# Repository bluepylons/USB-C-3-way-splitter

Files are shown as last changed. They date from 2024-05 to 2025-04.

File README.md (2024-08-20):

# A USB-C 3-way-splitter for charging multiple 5W devices from a single USB-PD charger

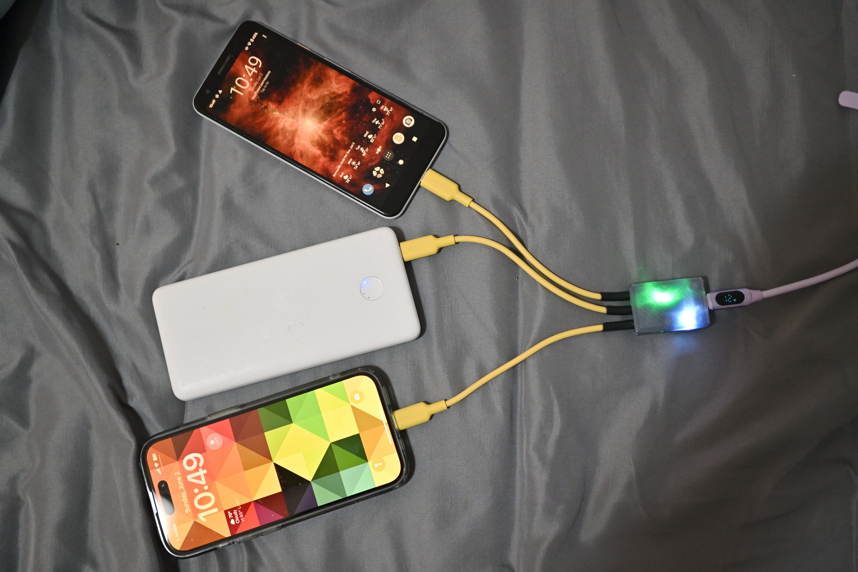
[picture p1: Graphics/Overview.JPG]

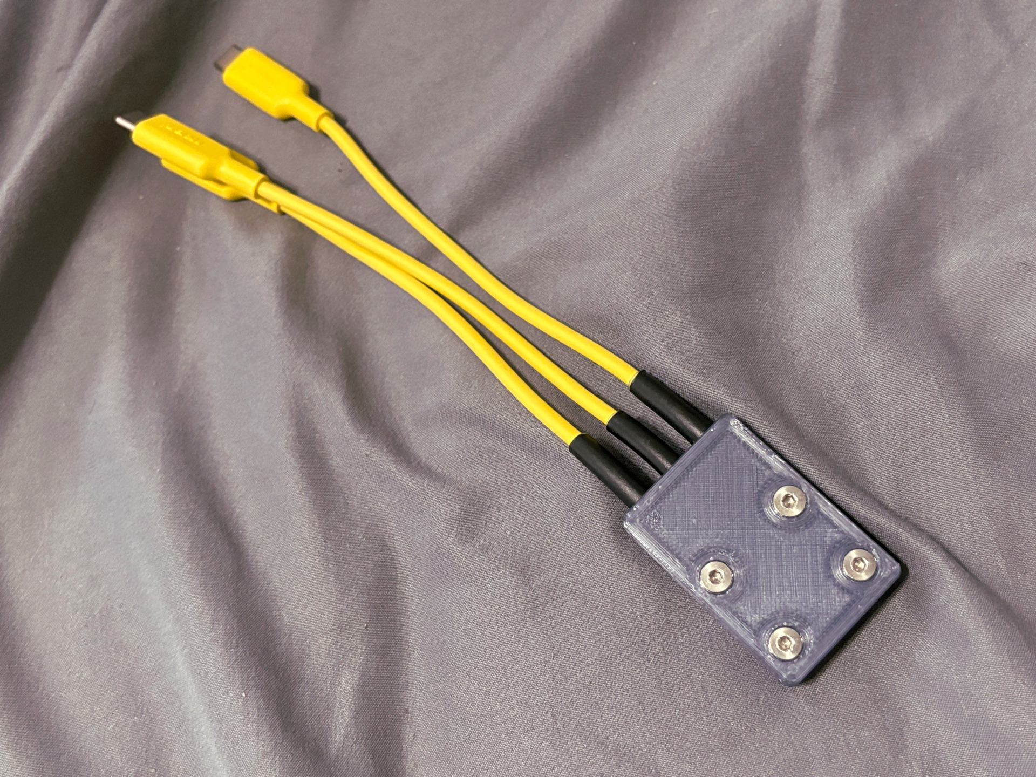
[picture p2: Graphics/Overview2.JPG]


*Disclaimer* - **Build and/or use this at your own  risk. I am not responsible for anything that arises from use of these files or documents, or for anything that arises from constructing and/or using this device.**

*Disclaimer 2* - the USB battery charging standard actually provides [for a maximum of 1.5A](https://imgur.com/07zPKKw), not 1A as originally believed. The polyfuse used (Littelfuse 1812L300MR) does not reliably trip below 5A, so this splitter may result in 4.5A maximum being drawn from the source. A planned Version 4 (which uses an 3A electronic fuse in place of the high-side switch to reliabily cut off current at around 3A) is being developed to address this issue. UPDATE August 19, 2024 - Version 4 does not work as the ENABLE pin logic for the electronic fuse was inverted. Version 5 is planned to fix this. 

This is a USB-C splitter that splits a 5V 3A-capable USB-C power source to 3 5V 1A  sources. This is for using a single-port USB-C PD charger to charge multiple 5V USB-C devices at once. Files are done in KiCAD 8, and manufacturing files for JLCPCB are provided. An enclosure design is included (which was designed in Autodesk Fusion 360) - .3mf, .step, and .f3z file are provided. 

This design has been prototyped and  tested. 

## Background
With the widespread adoption of USB-C for device charging, I can now travel with a single compact 45W USB-C GaN charger and cable, and charge all my USB-C devices (phone, laptop, camera, flashlight, power bank, headphones, etc.) with that one charger. However, having a single cable and single charger is often limiting when I need to charge multiple devices, especially overnight, and many USB-C devices only need 5V and not many watts for overnight charging. This splitter goes onto an existing USB-C cable, for charging those devices simultaneously with a single charger, without needing a bulkier multi-port charger and multiple cables. 

## Operation 
For safety, the splitter outputs only power on when the splitter is connected to a charger that indicates it can actually supply 3A, and includes a resettable fuse for overcurrent protection. The white LED lights up when it is connected to a powered USB-C cable. The green LED lights up if the power source is capable of supplying 5V 3A, and indicates the outputs have been powered on.

The outputs have D+ and D- shorted to indicate that they can supply ~~~1A~~~ 1.5A of current (per the USB Battery Charging standard). 

## Design
The splitter only powers on with USB-C inputs capable of supplying 5V 3A. This is done by monitoring the USB-C CC lines and checking that the signal there is greater than 1.25V. Under the USB-PD standard, if the voltage on the CC pin [is greater than 1.31V](https://hackaday.com/2023/01/04/all-about-usb-c-resistors-and-emarkers/), it indicates the source is capable of supplying 5V 3A. Only then are the outputs powered on (as indicated by the green LED). Otherwise, the outputs are turned off. 

The CC line voltage checking is done by a pair of comparators that monitor each of the 2 CC lines (as the USB-C input cable can be plugged in either way). The CC line voltage are compared against a 1.25V reference voltage (provided by an ST TS4061AICT-1.25 shunt diode reference) - a 1.31V voltage reference would have been more precise, but were not easily available, and 1.25V is above the 1.16V cutoff for a 1.5A source and works fine. The output of the comparators are fed through a pair of diodes (functioning as an OR gate) to the ENABLE input on an SiP32509 high-side switch that turns the outputs on and off. The device is over-current protected by a 3A resettable fuse (Littelfuse 1812L300MR). The CC lines and +5V bus are ESD protected with an SRV05-4 ESD diode array and an ESD5Z5V0 TVS diode.

Note that the output cables need 56K pull-up resistors between output CC and 5V to comply with the USB-C protocol - some devices may not charge if these resistors are missing. USB-A to USB-C cables are required to include this resistor, so using the USB-C end from a cut-up USB-A to C cable is recommended for the output cables. 

A 3D-printed enclosure design is supplied in the Enclosure folder. The enclosure design is meant to be 3D-printed in two halves; on mine these were printed with translucent PETG to allow the indicator LEDs to shine through. The lower enclosure features embedded M3 nuts - **the print must be paused at the appropriate layer and M3 nuts need to be inserted before the print resumes**. The two halves are screwed together with M3x8 countersunk screws. The enclosure is designed to use [Ikea  SITTBRUNN](https://www.ikea.com/us/en/p/sittbrunn-usb-a-to-usb-c-light-yellow-80539483/) USB-A to USB-C cables, as these are widely available and inexpensive. The ends are wrapped in Qualtek Q5-3X-3/16-01-QB48IN-25 adhesive heatshrink for strain relief. To dissipate heat from the SiP32509 high-side switch (U2), which is expected to generate about 0.4W of heat at 3A, either the enclosure must be potted to facilitate heat transfer, or a thermal pad must be used between the SiP32509 and the case. [Lower-enclosure-potted](https://github.com/bluepylons/USB-C-3-way-splitter/blob/main/Enclosure/Lower-enclosure-potted.3mf) has a small hole to inject potting compound (or hot glue, or silicone) into the case - use a high viscosity potting compound to avoid it getting in the input USB-C connector. [Lower-enclosure-thermal-pad](https://github.com/bluepylons/USB-C-3-way-splitter/blob/main/Enclosure/Lower-enclosure-thermal-pad.3mf) has a small raised feature above the SiP32509 IC to place a 1.5mm thick thermal pad between it and the case. 

# ORDERING GUIDE

## Bill Of Materials

### Custom Parts
| Description | Quantity  | Notes | 
| --- | --- | - |
| [PCB](https://github.com/bluepylons/USB-C-3-way-splitter/tree/main/Manufacturing%20files) | 1 | See "Ordering the PCB" section below  | 
| [Upper enclosure](https://github.com/bluepylons/USB-C-3-way-splitter/blob/main/Enclosure/Upper-enclosure.3mf) | 1 | FDM 3D-printed  |
| Lower enclosure ([thermal pad](https://github.com/bluepylons/USB-C-3-way-splitter/blob/main/Enclosure/Lower-enclosure-thermal-pad.3mf) or [potted](https://github.com/bluepylons/USB-C-3-way-splitter/blob/main/Enclosure/Lower-enclosure-potted.3mf)) | 1 | FDM 3D-printed. Has 4 embedded M3 nuts, which must be installed while 3D printing | 

The 3D-printed parts were FDM 3D-printed in PETG, though other materials probably work fine here. A translucent or semi-translucent material is recommended so that the indicator LEDs can shine through. 

## Off-the-shelf parts

| Description | Part number | Quantity | Notes | 
| --- | --- | --- | --- |
| [Ikea Sittbrunn USB-A to USB-C cable](https://www.ikea.com/us/en/p/sittbrunn-usb-a-to-usb-c-light-yellow-80539483/) | Ikea 805.394.83 | 3 | | 
| M3 hex nut, DIN 934, zinc-plated steel | McMaster-Carr 90591A250 | 4 | Generic. Not stainless steel to avoid galling |
| M3x8 flat head screw, DIN 7991 / ISO 10642, hex drive, 18-8 stainless steel | McMaster-Carr 92125A128 | 4 | Generic |
| Adhesive-lined heat-shrink, 3/16" / 4.8mm ID, 3:1 shrink ratio | Qualtek Qualtek Q5-3X-3/16-01-QB48IN-25  | 3x 25mm  | |

If you are using the [thermal pad option](https://github.com/bluepylons/USB-C-3-way-splitter/blob/main/Enclosure/Lower-enclosure-thermal-pad.3mf) for the lower enclosure, you will need 1.5mm thick thermal pads. I used Thermalright Extreme Odyssey 1.5mm pads for the ones I have built, but other 1.5mm thermal pads (e.g. Arctic TP-3) may work. The thermal pad must not be electrically conductive. 

If you are using the [potted option](https://github.com/bluepylons/USB-C-3-way-splitter/blob/main/Enclosure/Lower-enclosure-potted.3mf) for the lower enclosure, you will need some sort of potting compound that can be injected through a 5mm diameter hole. The ones I built used hot glue. Make sure the potting compound has high enough viscosity to not get into the input USB-C port. 

## Ordering the PCB

The PCB can be ordered from [JLCPCB](https://jlcpcb.com/) in China, and the files are provided in their format. 

1.)  Go to JLCPCB, and press "Order Now". 
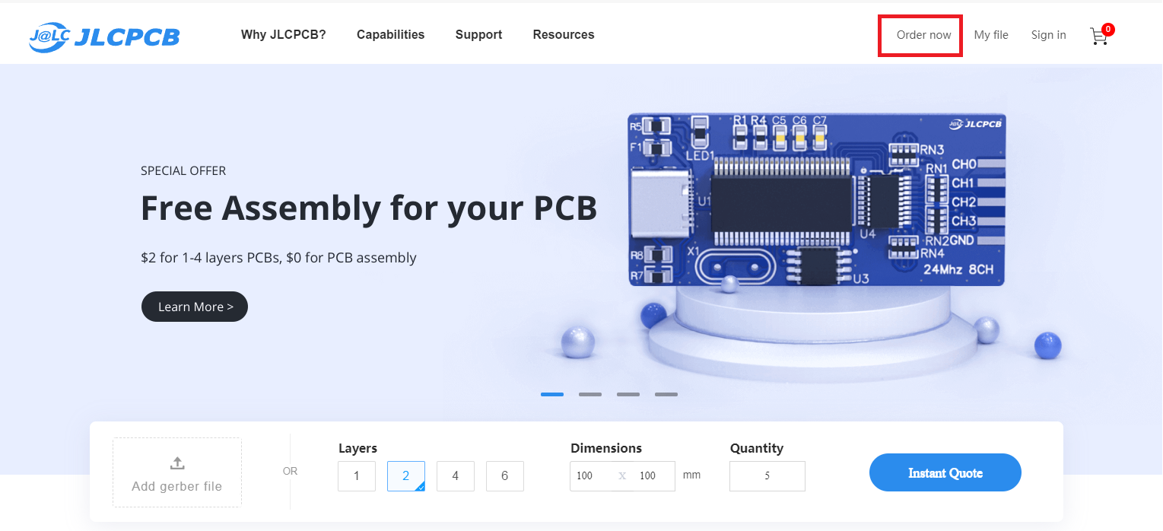
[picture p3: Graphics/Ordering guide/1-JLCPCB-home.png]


2.) Next, you want to upload the [Gerber ZIP file](https://github.com/bluepylons/USB-C-3-way-splitter/blob/main/PCB%20manufacturing%20files/V3%20Gerbers.zip) for the PCB. 
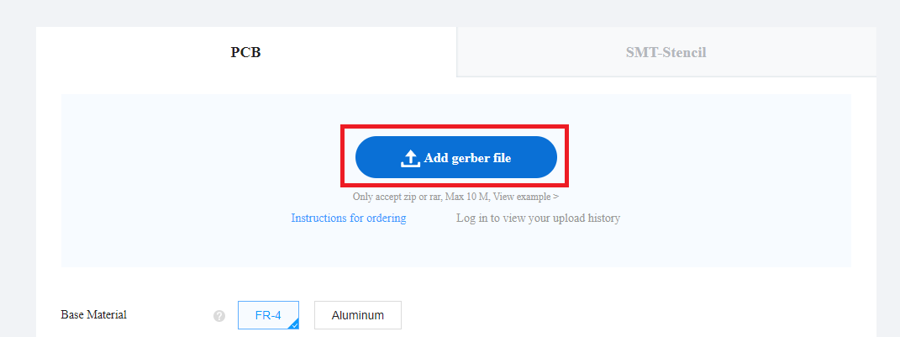
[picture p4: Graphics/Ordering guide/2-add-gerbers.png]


3.) Specify the following options once the Gerber file has uploaded. Non-default settings are highlighted in red. 
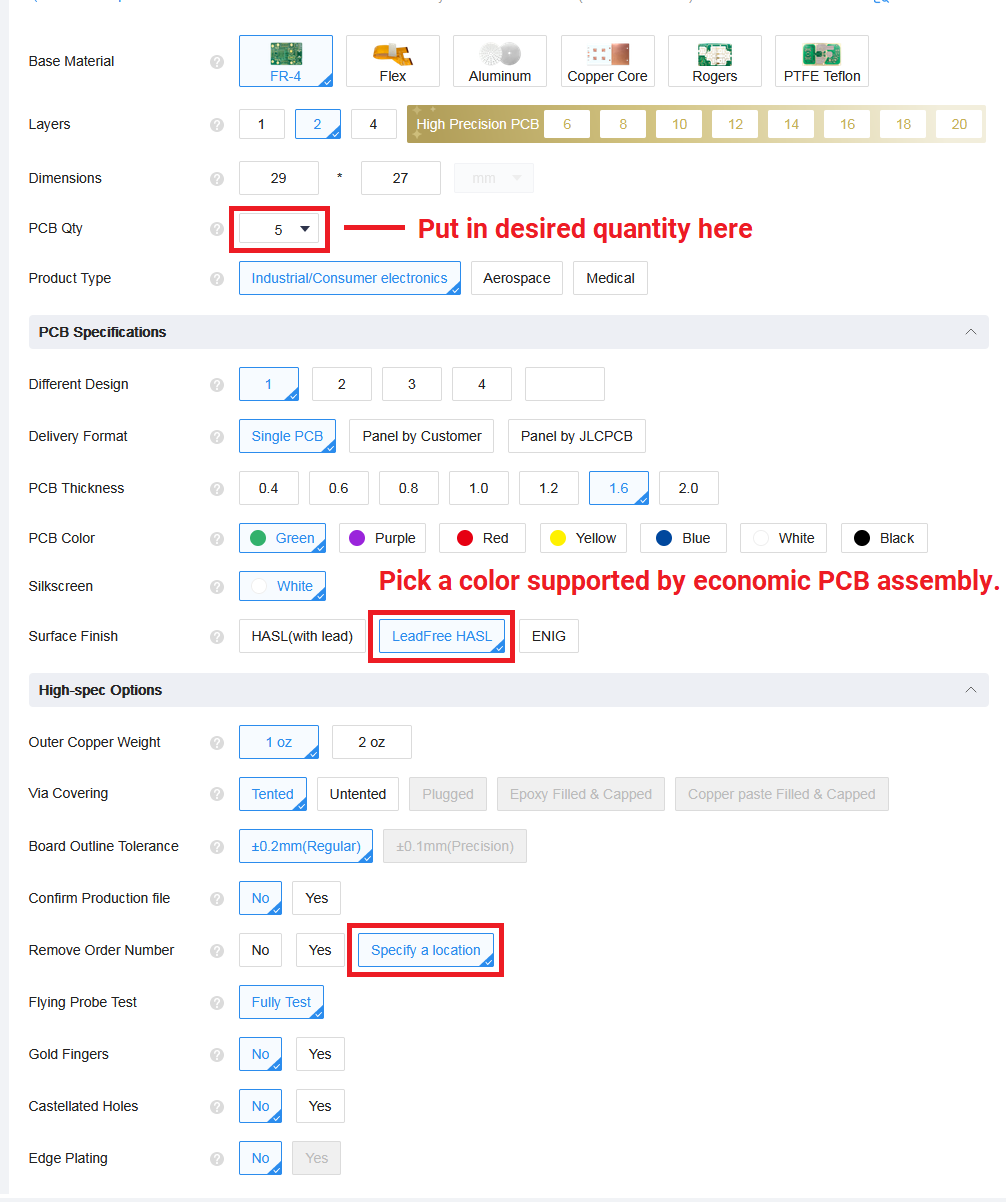
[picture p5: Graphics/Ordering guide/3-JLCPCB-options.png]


For color, specify a color supported by JLCPCB's ["Economic PCB Assembly"](https://jlcpcb.com/capabilities/pcb-assembly-capabilities). As of June 30, 2024, green, black, blue, red, white, and purple are supported. Note that some colors might incur an extra fee.

4.) Under "PCB Assembly", specify the following options:
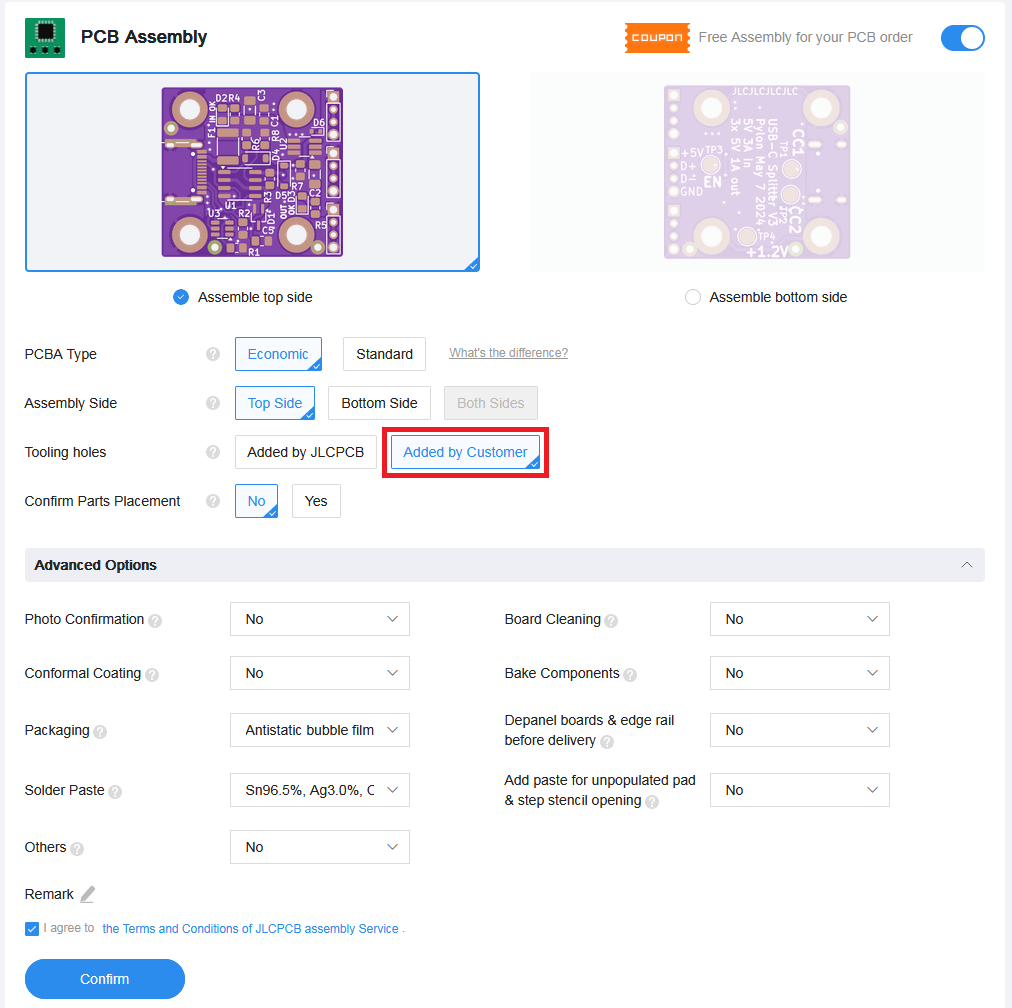
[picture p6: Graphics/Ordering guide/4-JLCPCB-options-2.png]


5.) Press "Next":

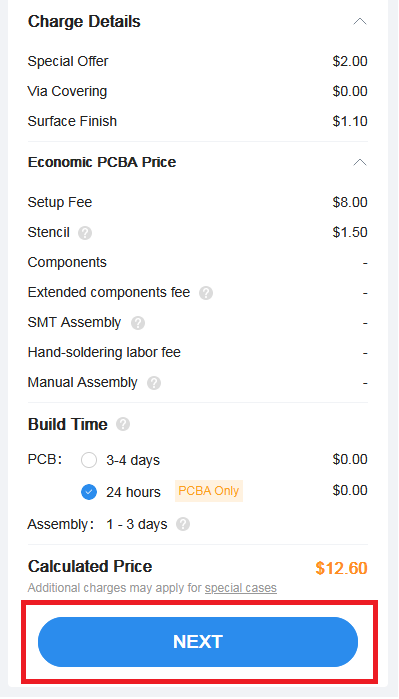
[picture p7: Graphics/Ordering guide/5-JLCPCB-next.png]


6.) Upload the [BOM](https://github.com/bluepylons/USB-C-3-way-splitter/blob/main/PCB%20manufacturing%20files/JLCPCB-BOM.xls) and [CPL](https://github.com/bluepylons/USB-C-3-way-splitter/blob/main/PCB%20manufacturing%20files/JLCPCB-CPL.xls) files:
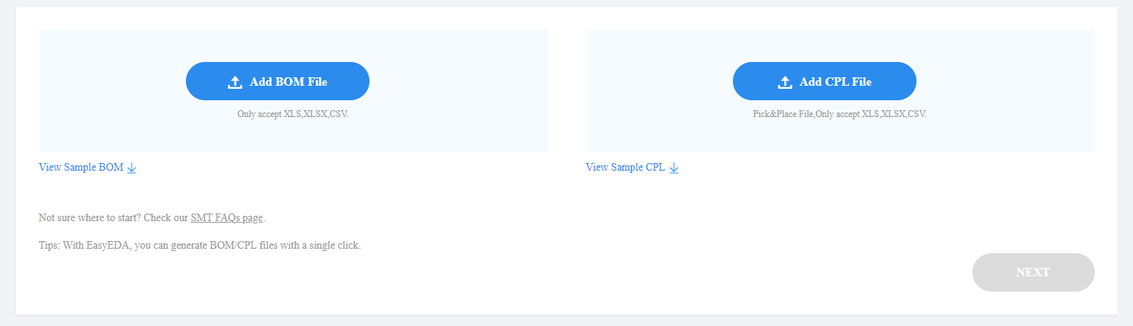
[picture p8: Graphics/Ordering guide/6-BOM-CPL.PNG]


7.) Confirm  the components in the next page. If any components are listed as "Shortfall", JLCPCB does not have enough of them in stock and will not install them on any PCBs. You will have to purchase them from and solder them on yourself. Alternatively, you can wait for JLCPCB to restock the part.
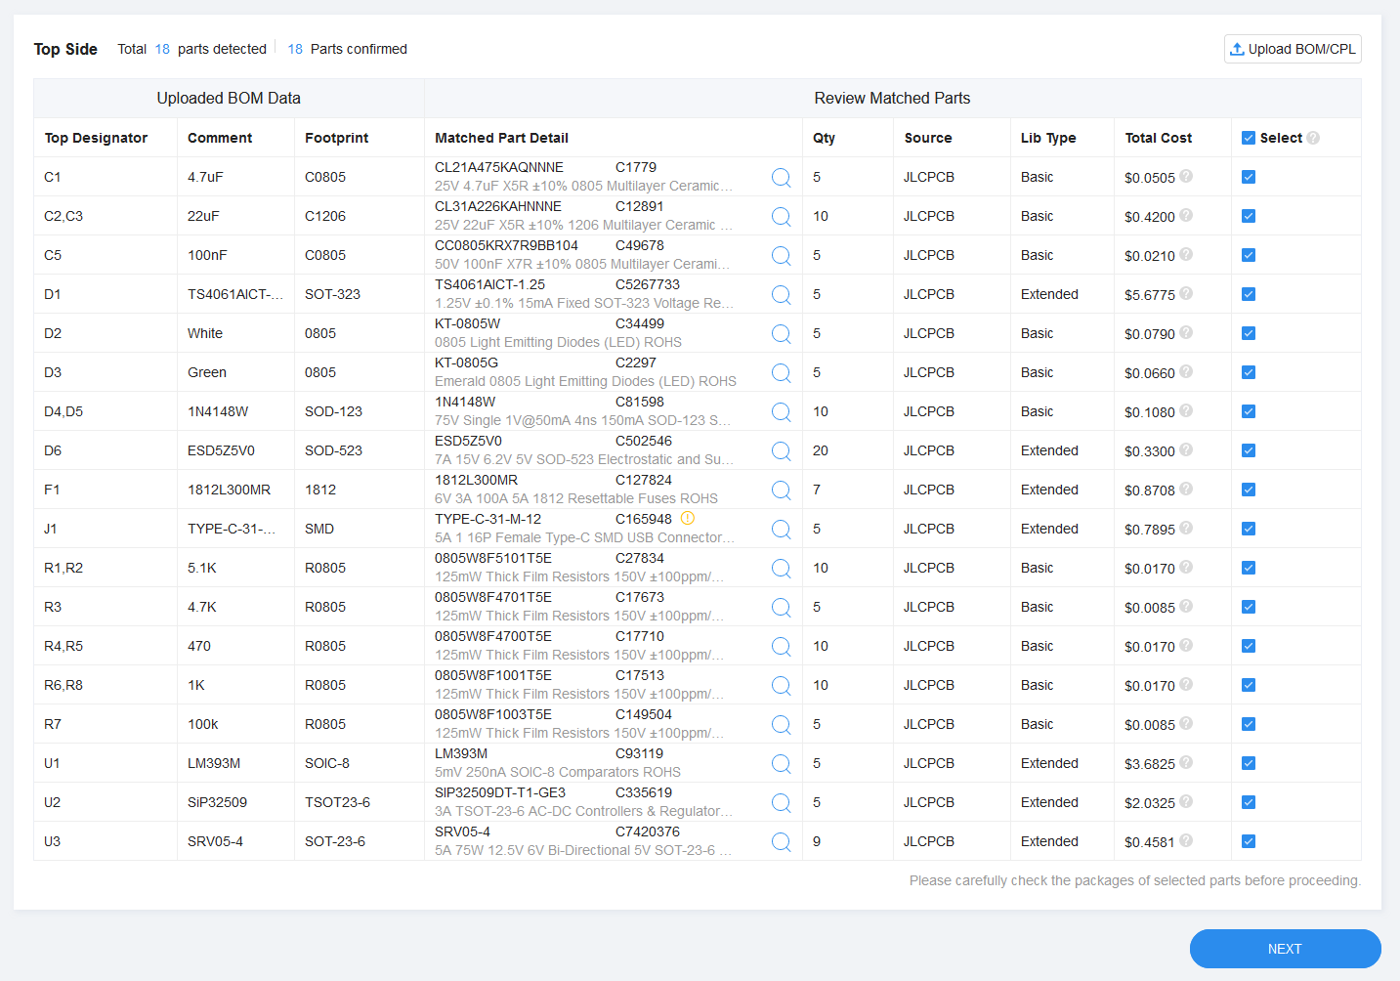
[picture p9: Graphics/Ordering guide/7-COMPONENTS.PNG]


8.) Next is the component placement confirmation page. You should not have to change anything here:
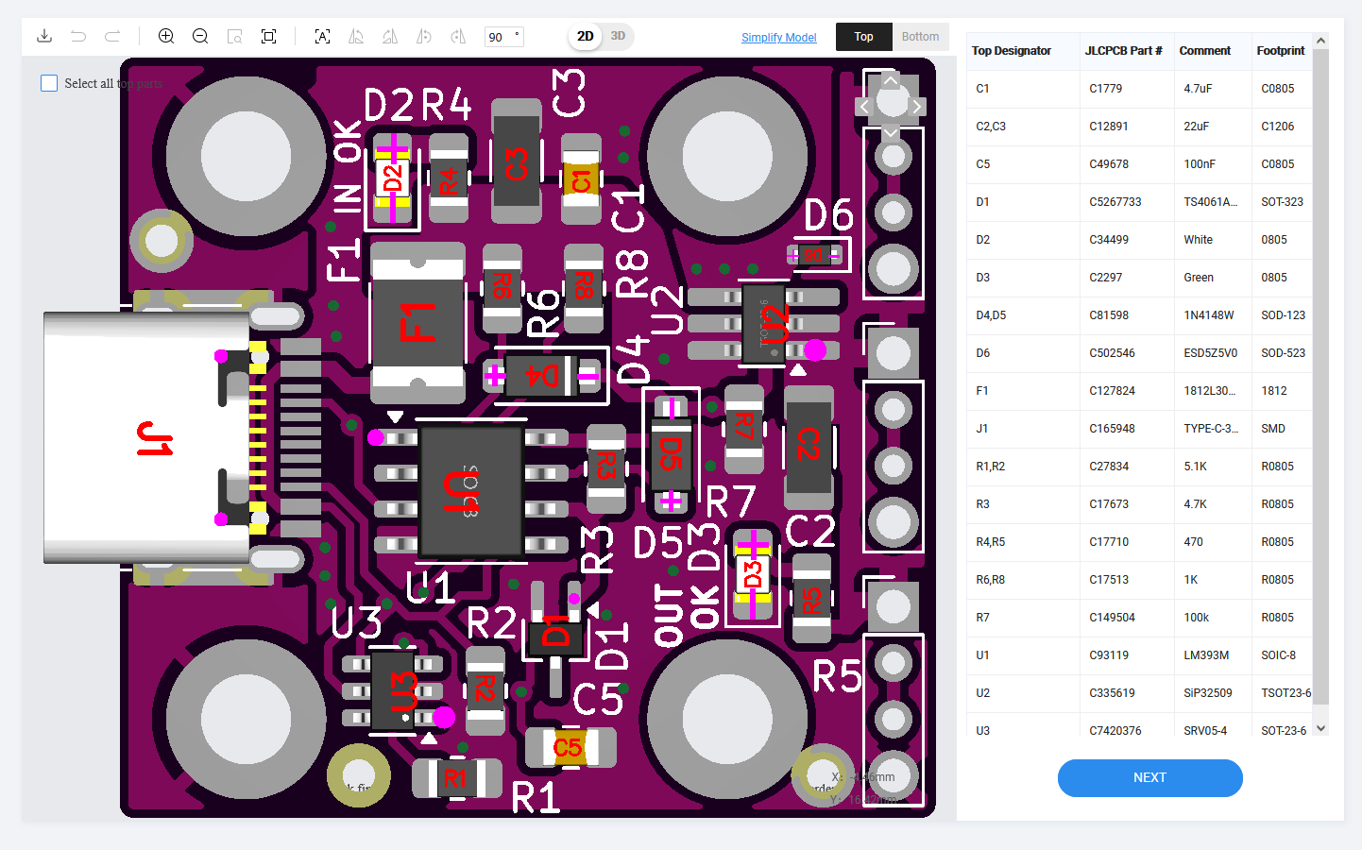
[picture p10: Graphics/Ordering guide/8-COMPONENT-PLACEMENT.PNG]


9.) You will need to describe the item in the next page for customs purposes. As of June 30th, 2024, I could not find an option most suitable for this, so select "Office Appliances and Accessories > Others" in the options, and type in "USB cable splitter PCB".
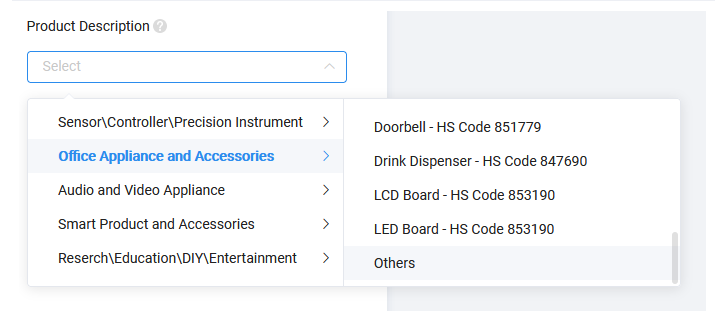
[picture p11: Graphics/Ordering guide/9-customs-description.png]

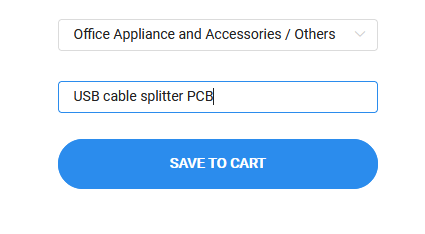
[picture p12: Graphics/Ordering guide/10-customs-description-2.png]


# BUILD GUIDE

## Tools needed 
| Tool | Purpose |
| --- | --- |
| Flush cutters  | Stripping wires, trimming leads |
| Soldering iron | Soldering the USB-C output cables to the PCB |
| Solder | You need it to solder |
| Flux | Makes tinning the output cables easier |
| Heat gun | For the heat-shrink strain relief |
| Wire strippers | For stripping wire |

If you are using the thermal pad option for the lower case, you will need scissors to cut the thermal pad. If you are using the potted option, you will need potting compound and whatever tools needed to inject into the hole in the case.

## Build process 

1.) Test the PCB by plugging in a 5V 3A-capable USB-C source. When plugged in, both the white and green LEDs should light up. Next, test it with a non-5V 3A capable source (e.g. use a USB-A cable). When plugged in, only the white LED should light up. 

2.) Unplug the PCB. 

3.) Take the Ikea Sittbrunn USB-A to USB-C cable, and cut the USB-C end to about 20-30mm longer than the desired length.
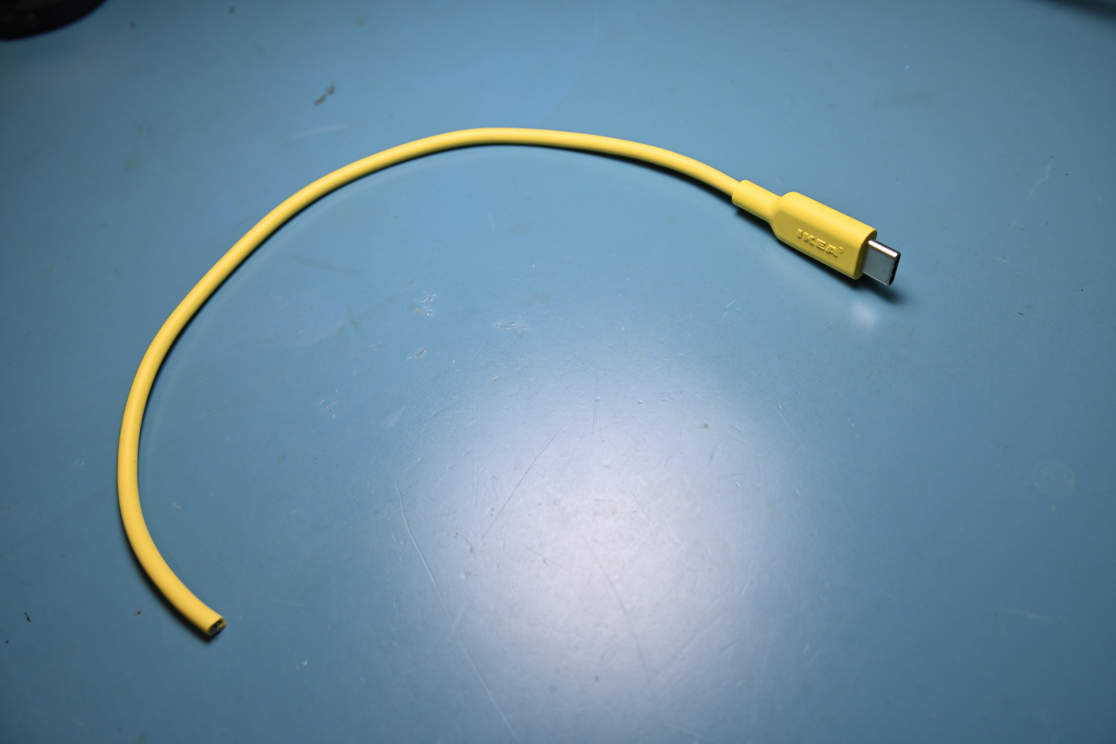
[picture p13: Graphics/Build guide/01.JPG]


4.) Strip about 20mm off the outer insulation. The method I found works well is to use a pair of flush cutters to "bite' the insulation parallel to the cable, and then cut the resulting pieces off. After stripping, check that the insulation for the individual wires are not damaged. 

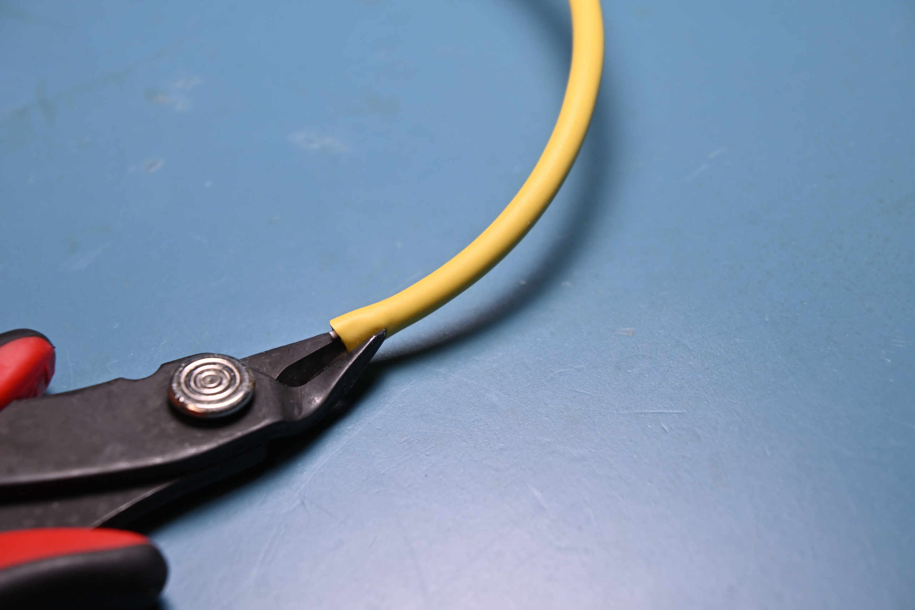
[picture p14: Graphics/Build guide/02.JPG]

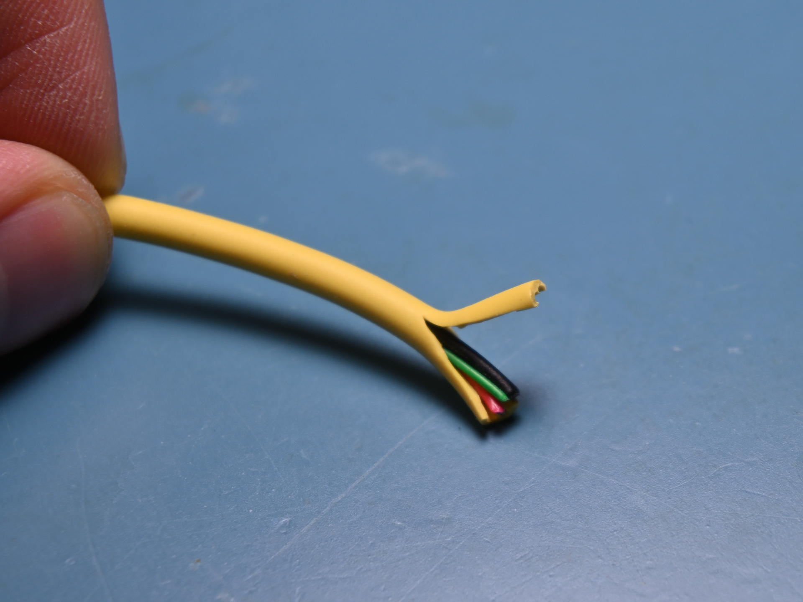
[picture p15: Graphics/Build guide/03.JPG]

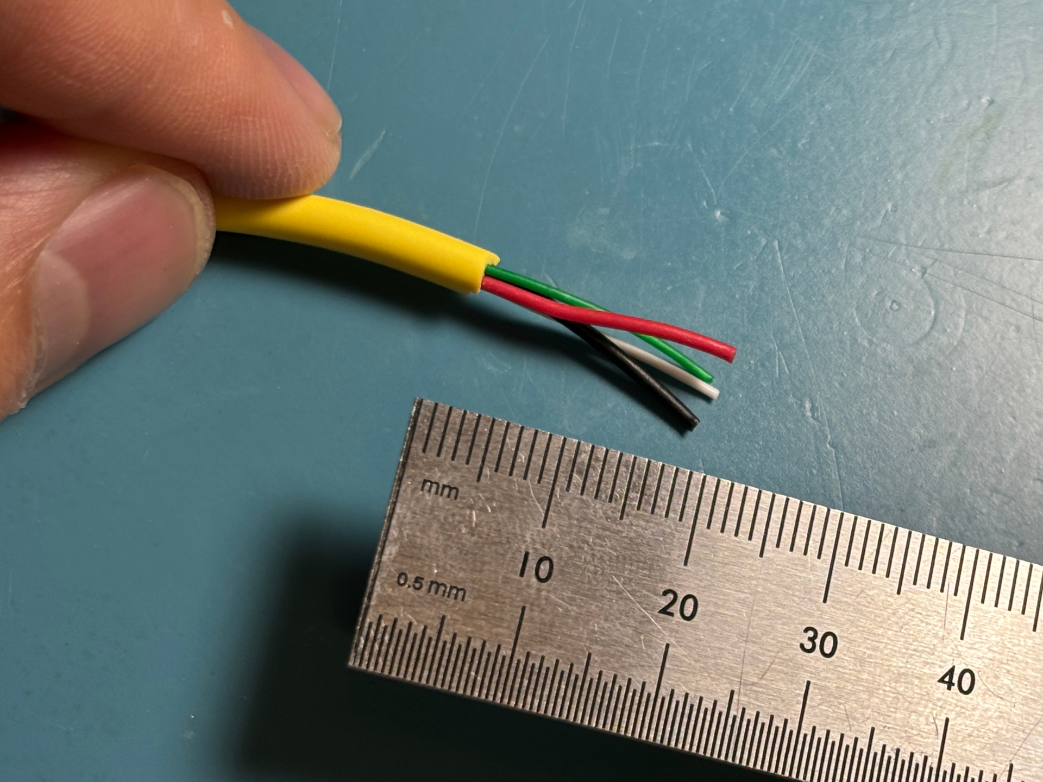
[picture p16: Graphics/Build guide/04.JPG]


5.) Strip about 10mm off the inner insulation for one of the wires.
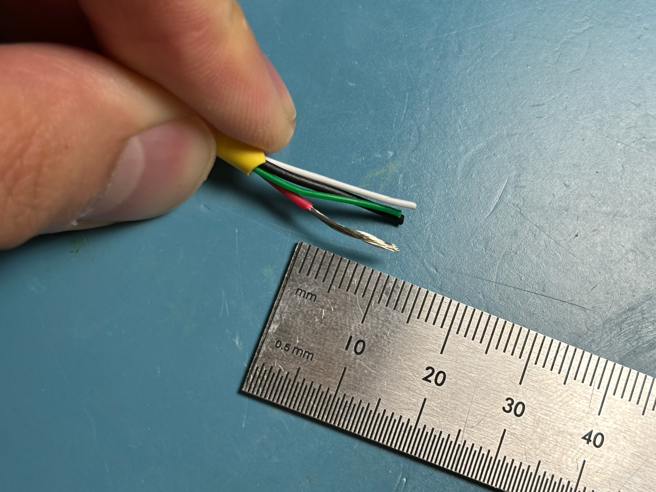
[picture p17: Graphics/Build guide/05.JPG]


6.) Wind  the strands tightly with your hands. 
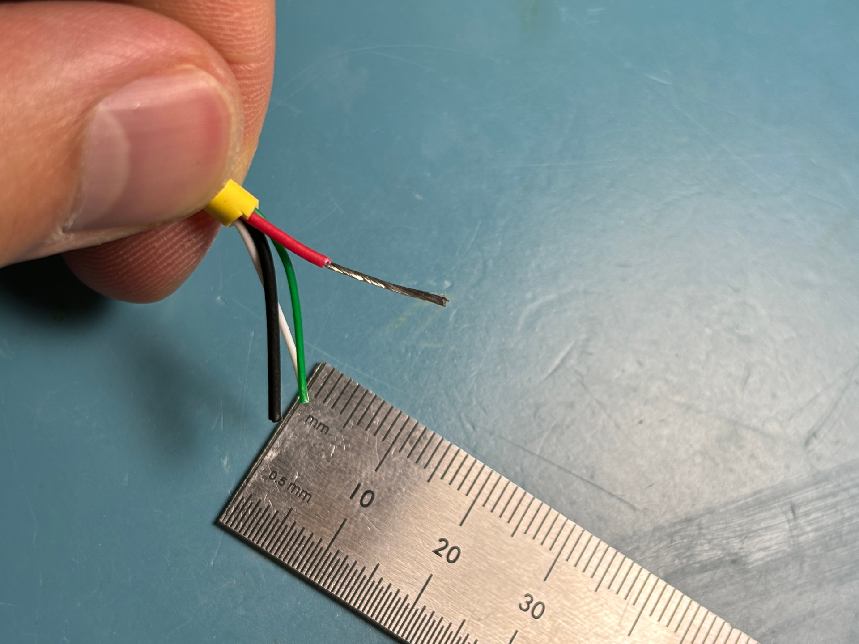
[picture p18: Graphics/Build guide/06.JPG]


7.) Apply some flux to the stripped wire.
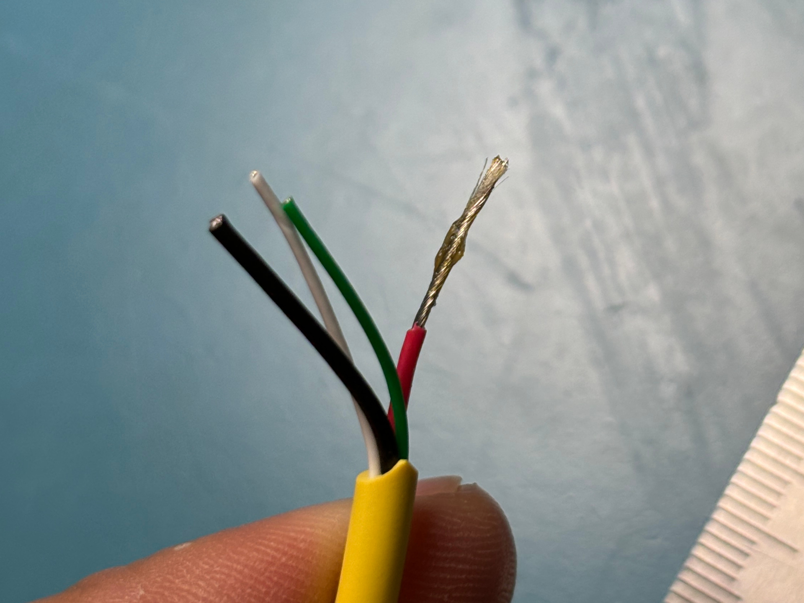
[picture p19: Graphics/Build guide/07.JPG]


8.) Tin the wire with a little bit of solder. Try to add enough solder here that the strands don't come apart, but not so much that the stranded wires no longer fit in the output footprint through-holes in the PCB. 
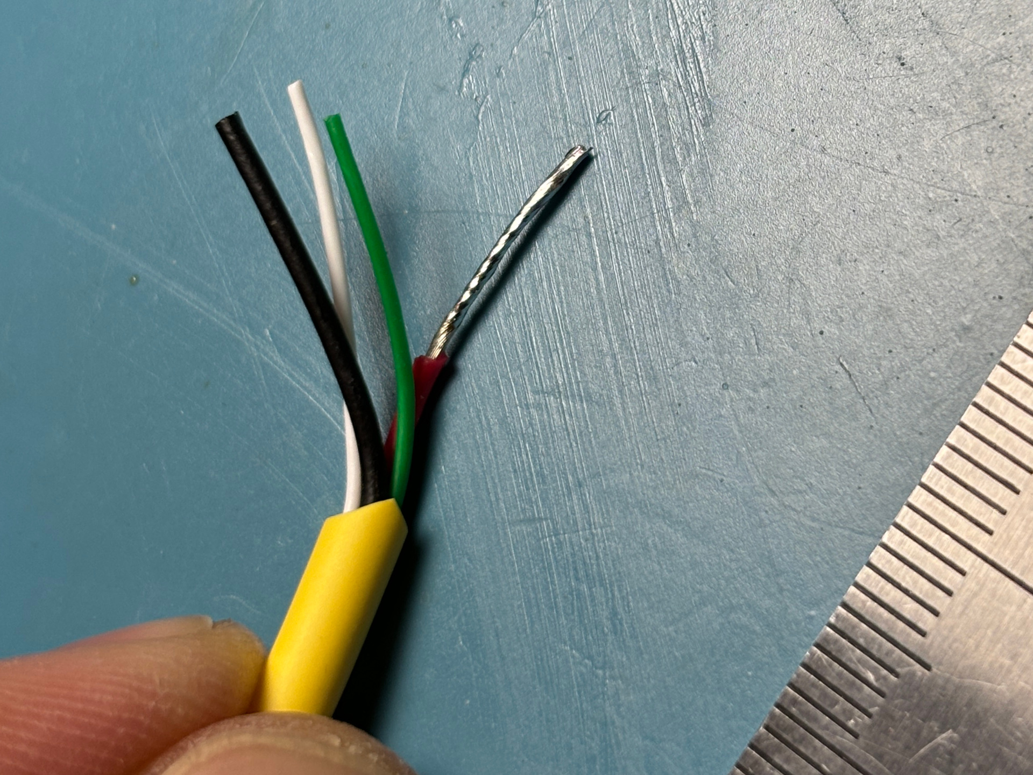
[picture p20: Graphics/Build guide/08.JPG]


9.) Repeat Steps 5 through 8 for the remaining wires. This is best done one wire at a time to prevent the wires from becoming unstranded from bumping into each other. 
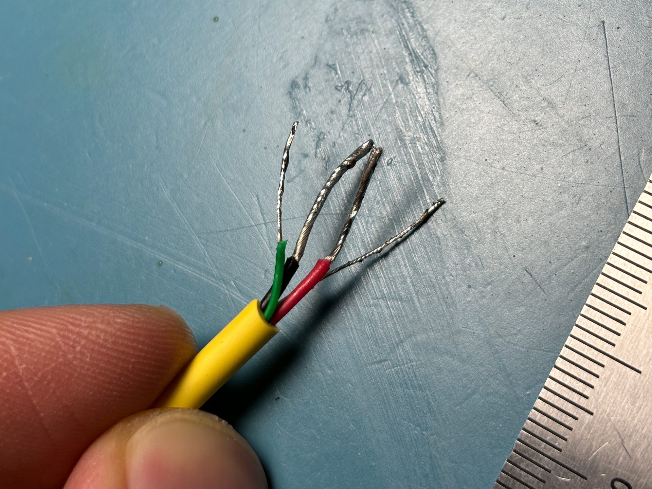
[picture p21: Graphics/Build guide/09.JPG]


10.) Cut some pieces of heat-shrink that are 20-30mm long:
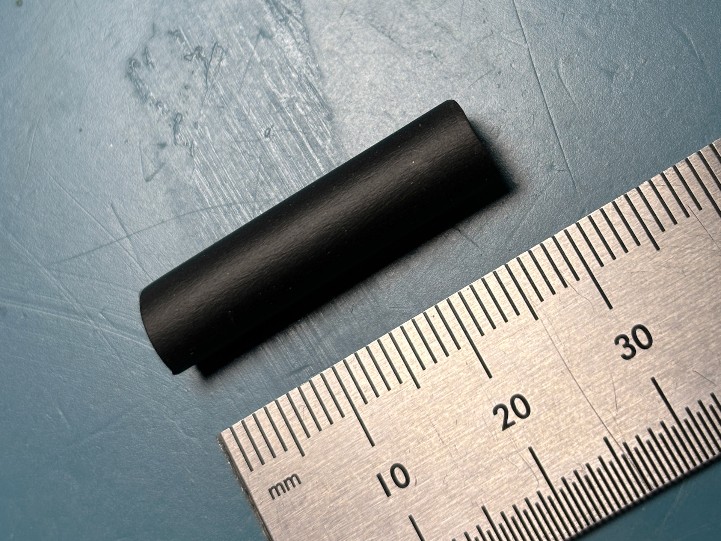
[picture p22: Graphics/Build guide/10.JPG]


11.) Put the heat shrink through the cable.
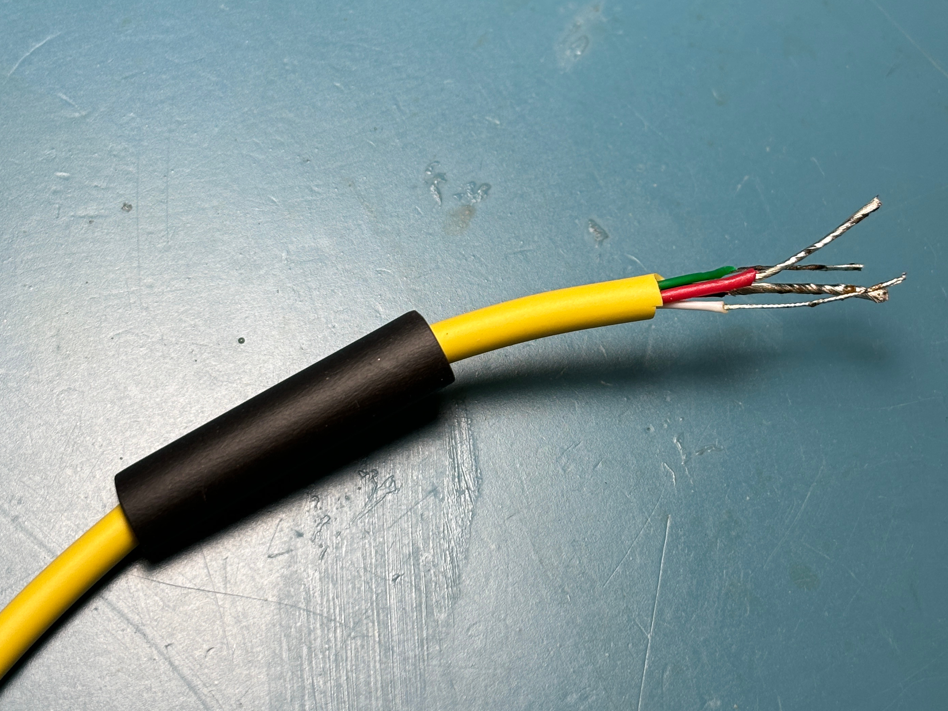
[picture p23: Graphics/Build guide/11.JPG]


12.) Solder the wires to one of the three output footprints, and trim off any excess using the flush cutters.

The following wire colors correspond to the following pins, which are labelled on the underside of the PCB:

| Color | Pin |
| ----- | --- |
| Black | GND |
| Green | D-  |
| White | D+  |
| Red | +5V |

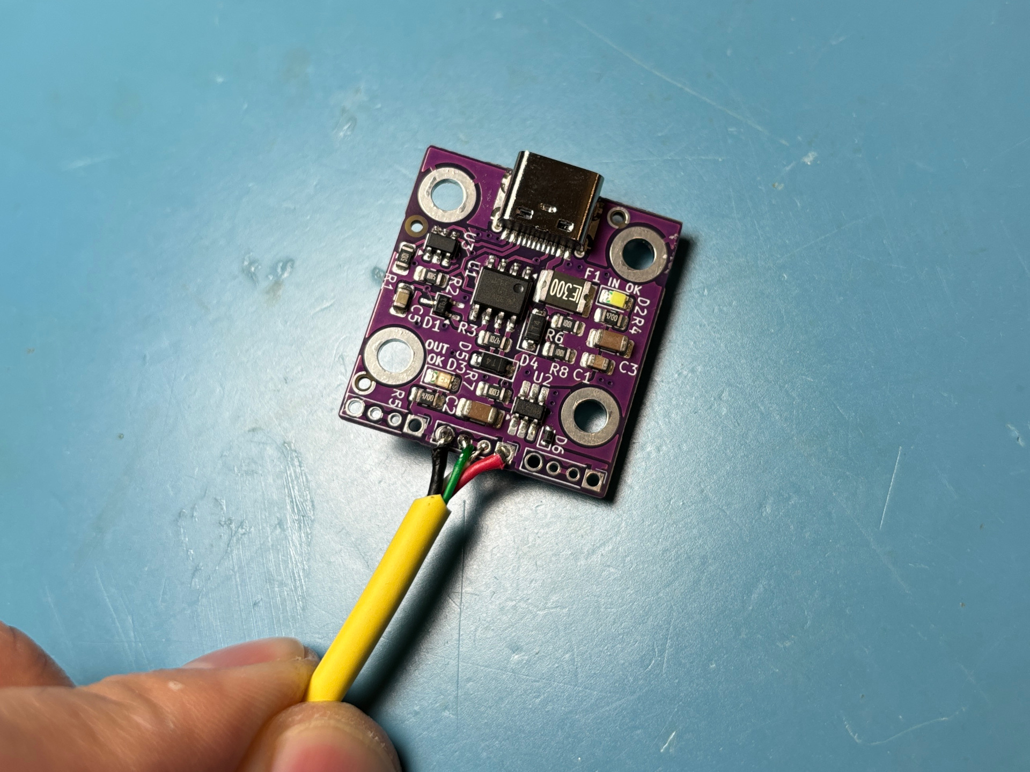
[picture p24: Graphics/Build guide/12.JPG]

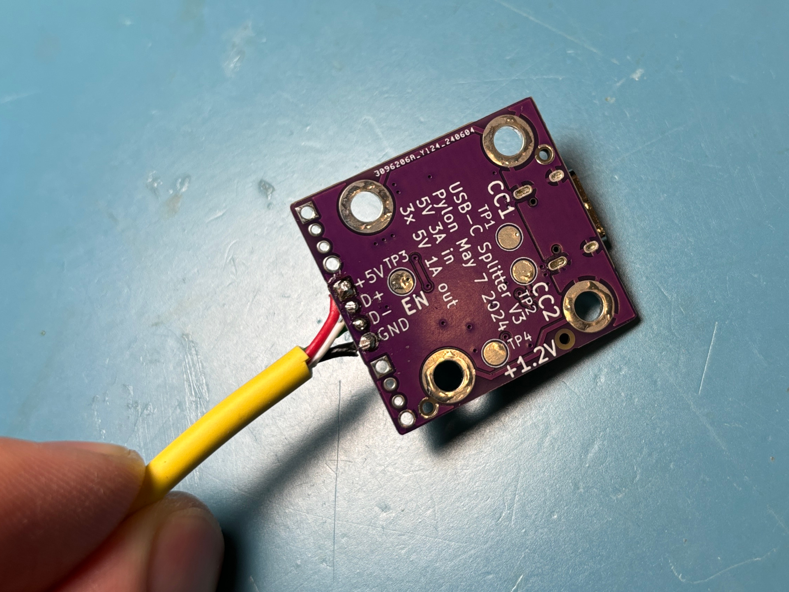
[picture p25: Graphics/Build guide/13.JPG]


Check that the strands from each wire are not shorted to each other. However, since D+ and D- are shorted to each other on the PCB per the USB Battery Charging standard, it does not matter if those two specific wires are shorted to each other. 

13.) Repeat steps 3-12 for the remaining outputs. **Remember to slip the heatshrink tubing on before soldering**. Double check that wires are not shorted to each other. 
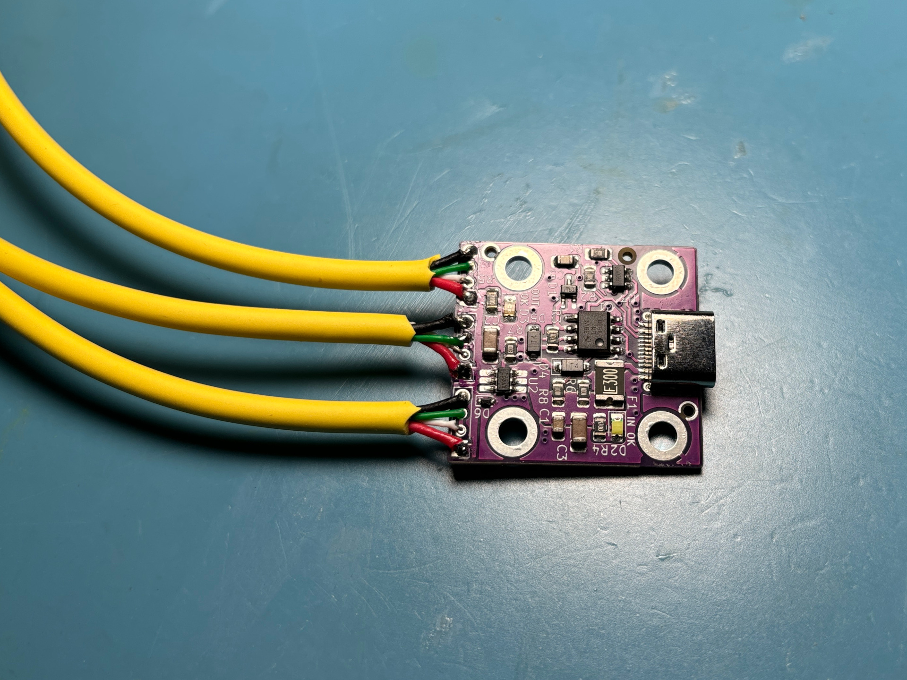
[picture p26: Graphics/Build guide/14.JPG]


14.) Plug the PCB into the 5V 3A USB-C source again. Check that the green and the white lights both light up. If not, you may have a short circuit somewhere.

15.) Move the heatshrink tubing down the cables, like so:
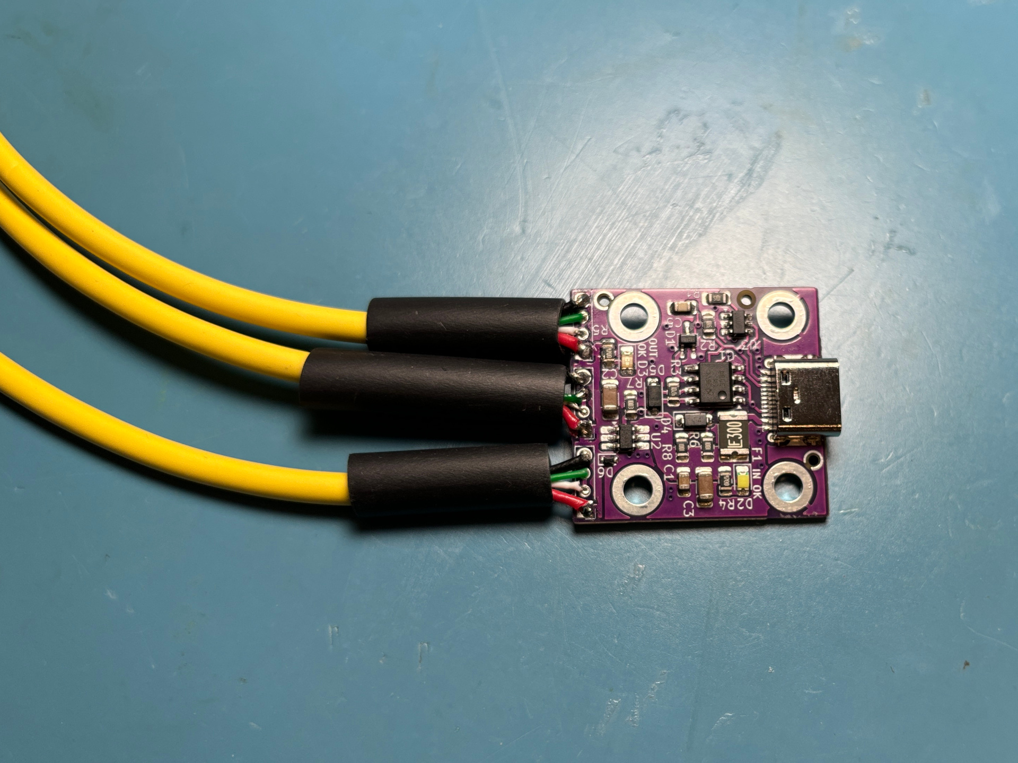
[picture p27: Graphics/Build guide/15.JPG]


17.) Using a heatgun, shrink the heatshrink:
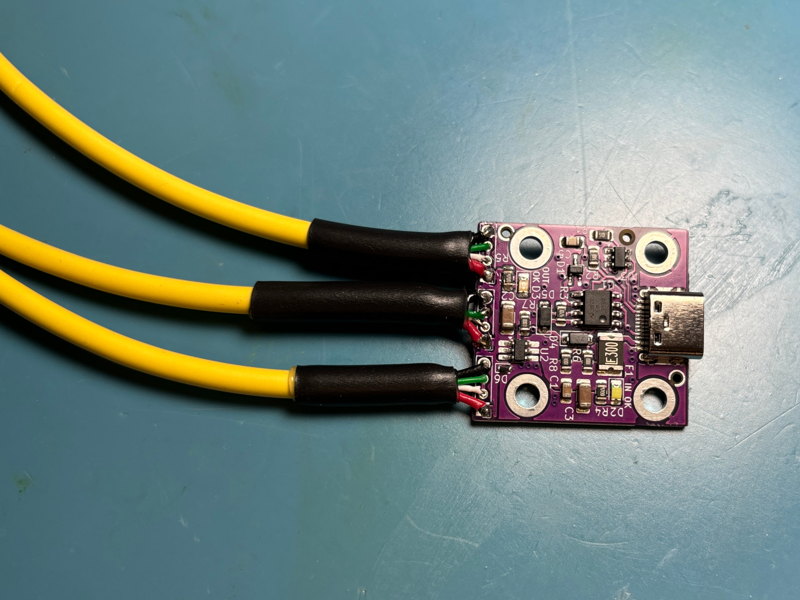
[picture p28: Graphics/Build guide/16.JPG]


18.) (For the thermal pad variant only) - Cut a piece of thermal pad to about the size and shape of the raised portion marked in red, and place it on there:
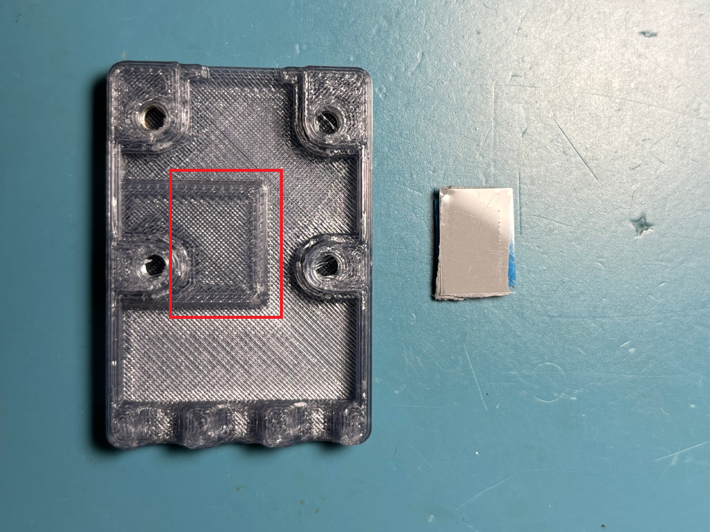
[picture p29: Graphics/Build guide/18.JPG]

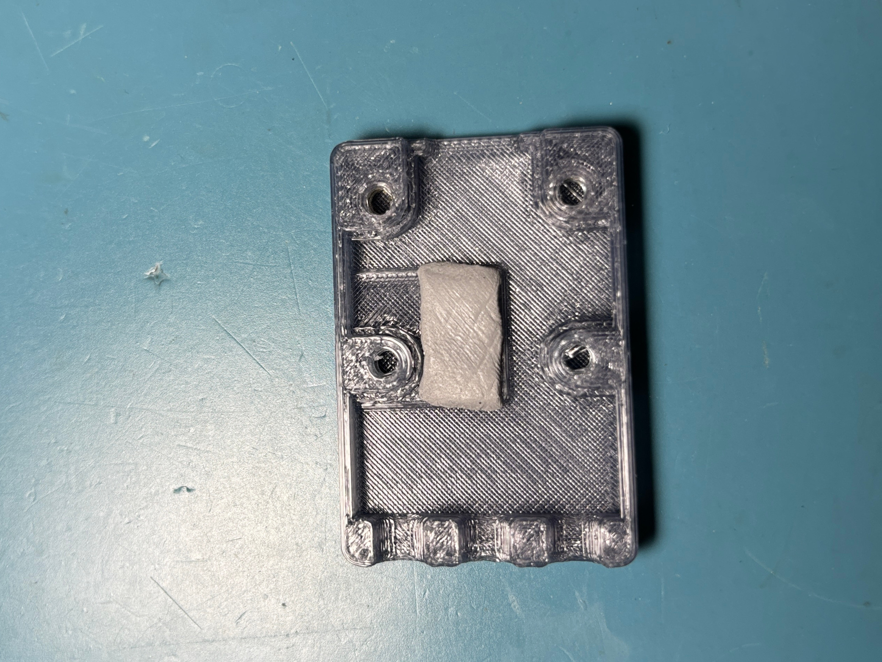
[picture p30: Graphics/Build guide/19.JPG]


19.) Place the PCB and the soldered wires onto the lower enclosure like so:
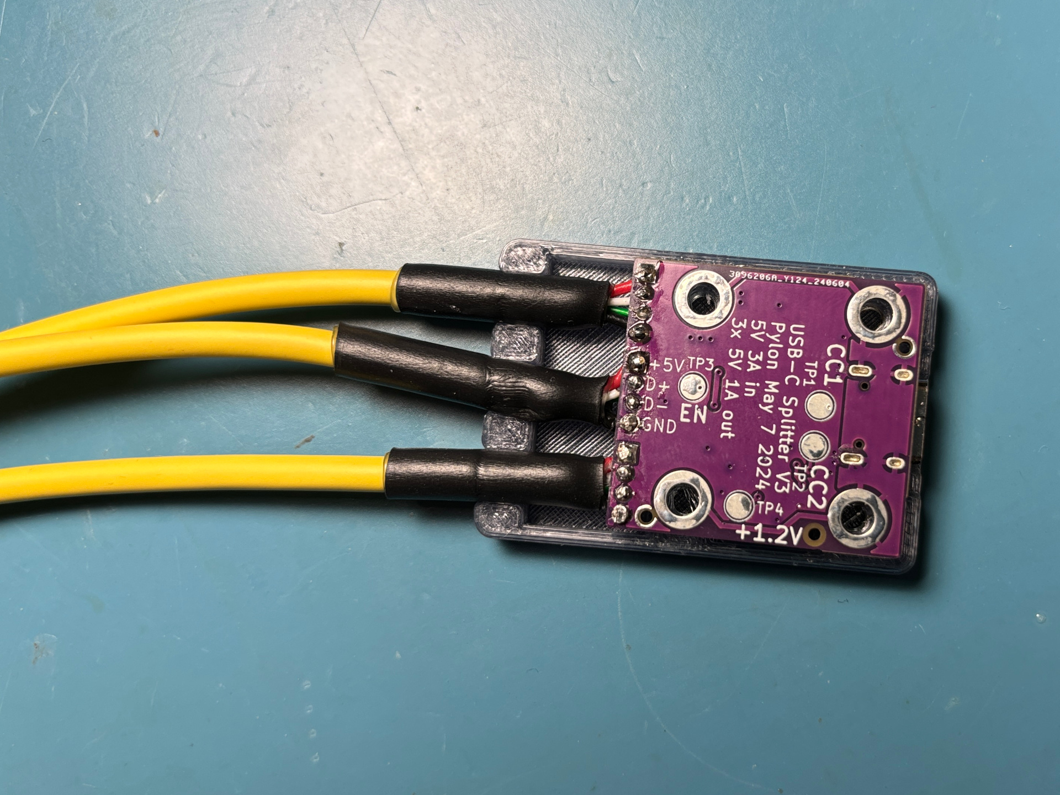
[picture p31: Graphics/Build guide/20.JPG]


20.) Place the upper enclosure on, and attach it with the 4 M3x8 flat head screws.
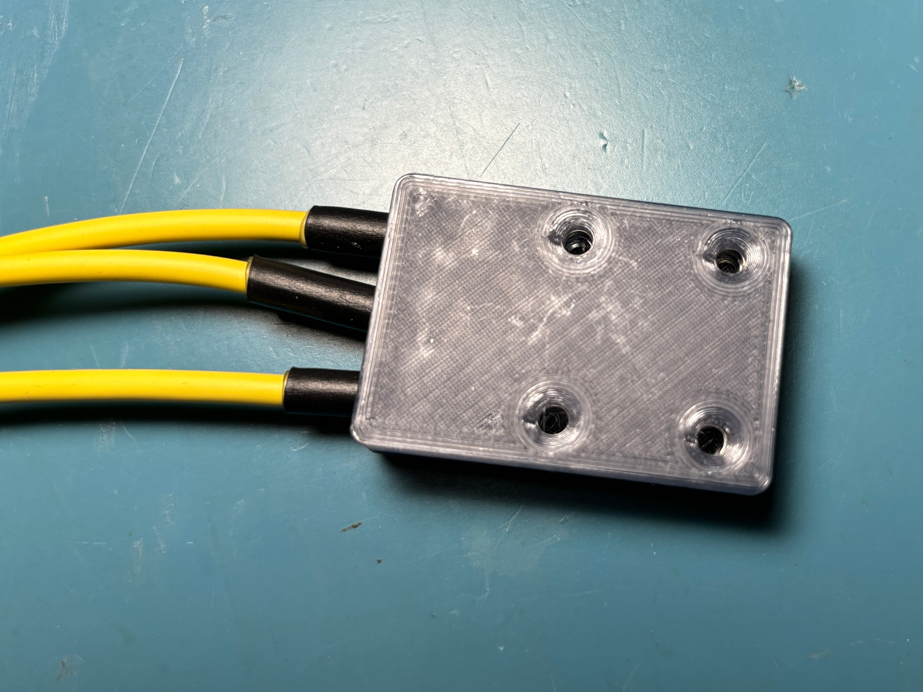
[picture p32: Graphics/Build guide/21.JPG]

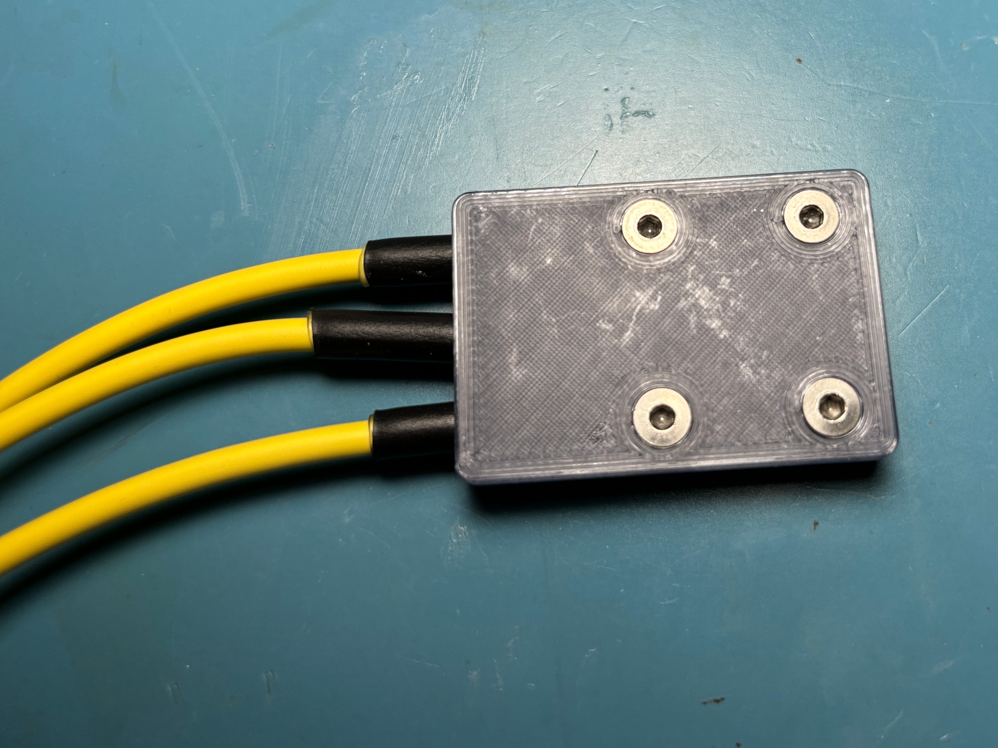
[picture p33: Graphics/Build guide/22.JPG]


21.) Test the splitter by plugging it into the 5V 3A source again, and using it to charge various devices (e.g. a phone). Make sure each output works. If not, check your soldering. 

22.) (For the potted variant only) - Inject potting compound into the 5mm hole on the lower enclosure, and it let it dry/solidify/cure. 

You are done!

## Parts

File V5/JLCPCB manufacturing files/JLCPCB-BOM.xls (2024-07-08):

Comment | Designator | Footprint | LCSC Part Number | Type
4.7uF | C1 | C0805 | C28323 | Basic
100nF | C5 | C0805 | C49678 (https://lcsc.com/product-detail/Multilayer-Ceramic-Capacitors-MLCC-SMD-SMT_100nF-104-10-50V_C49678.html) | Basic
22uF | C2,C3 | C1206 | C12891 | Basic
TS4061AICT-1.25 | D1 | SOT-323 | C5267733 | Extended
White | D2 | 0805 | C34499 | Basic
Green | D3 | 0805 | C2297 | Basic
1N4148W | D4,D5 | SOD-123 | C81598 | Basic
ESD5Z5V0 | D6 | SOD-523 | C502546 | Extended
1812L300MR | F1 | 1812 | C127824 | Extended
TYPE-C-31-M-12 | J1 | SMD | C165948 | Extended
5.1K | R1, R2 | R0805 | C27834 (https://lcsc.com/product-detail/Chip-Resistor-Surface-Mount_UNI-ROYAL-Uniroyal-Elec-0805W8F5101T5E_C27834.html) | Basic
4.7K | R3 | R0805 | C17673 | Basic
470 | R4,R5 | R0805 | C17710 | Basic
1K | R6,R8,R9 | R0805 | C17513 | Basic
20k | R7 | R0805 | C4328 | Basic
LM393M | U1 | SOIC-8 | C93119 | Extended
NIS6452MT1TWG | U2 | WQFN-12(2x3) | C893386 | Extended
SRV05-4 | U3 | SOT-23-6 | C7420376 | Extended
2N7002 | Q1 | SOT-23 | C8545 | Basic

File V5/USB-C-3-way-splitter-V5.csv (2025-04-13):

Id | Designator | Footprint | Quantity | Designation | Supplier and ref
1 | H4,H2,H1,H3 | MountingHole_3.2mm_M3_ISO7380_Pad | 4 | MountingHole_Pad
2 | F1 | Fuse_1812_4532Metric_Pad1.30x3.40mm_HandSolder | 1 | 1812L300MR
3 | D1 | SOT-323_SC-70_Handsoldering | 1 | D_Zener
4 | Q1 | SOT-23 | 1 | 2N7002
5 | R1,R2 | R_0805_2012Metric_Pad1.20x1.40mm_HandSolder | 2 | 5.1k
6 | J3,J2,J4 | PinHeader_1x04_P2.00mm_Vertical | 3 | Conn_01x04
7 | U1 | SOIC-8_3.9x4.9mm_P1.27mm | 1 | LM393
8 | R3 | R_0805_2012Metric_Pad1.20x1.40mm_HandSolder | 1 | 4.7k
9 | R7 | R_0805_2012Metric_Pad1.20x1.40mm_HandSolder | 1 | 20k
10 | C3,C2 | C_1206_3216Metric_Pad1.33x1.80mm_HandSolder | 2 | 22uF
11 | D2,D3 | LED_0805_2012Metric_Pad1.15x1.40mm_HandSolder | 2 | LED
12 | C5 | C_0805_2012Metric_Pad1.18x1.45mm_HandSolder | 1 | 100nF
13 | U2 | OnSemi-WQFN12-3x2mm_P0.5mm | 1 | ~
14 | R6 | R_0805_2012Metric_Pad1.20x1.40mm_HandSolder | 1 | 1K
15 | R5,R4 | R_0805_2012Metric_Pad1.20x1.40mm_HandSolder | 2 | 470
16 | C1 | C_0805_2012Metric_Pad1.18x1.45mm_HandSolder | 1 | 1uF
17 | H7,H6,H5 | JLCPCB-tooling-hole | 3 | MountingHole
18 | D5,D4 | D_SOD-123 | 2 | 1N4148W
19 | R9,R8 | R_0805_2012Metric_Pad1.20x1.40mm_HandSolder | 2 | 1k
20 | D6 | D_SOD-523 | 1 | D_Zener
21 | U3 | SOT-23-6 | 1 | SRV05-4
22 | J1 | USB_C_Receptacle_HRO_TYPE-C-31-M-12 | 1 | USB_C_Receptacle_USB2.0
23 | TP4,TP2,TP3,TP1 | TestPoint_Pad_D2.5mm | 4 | TestPoint

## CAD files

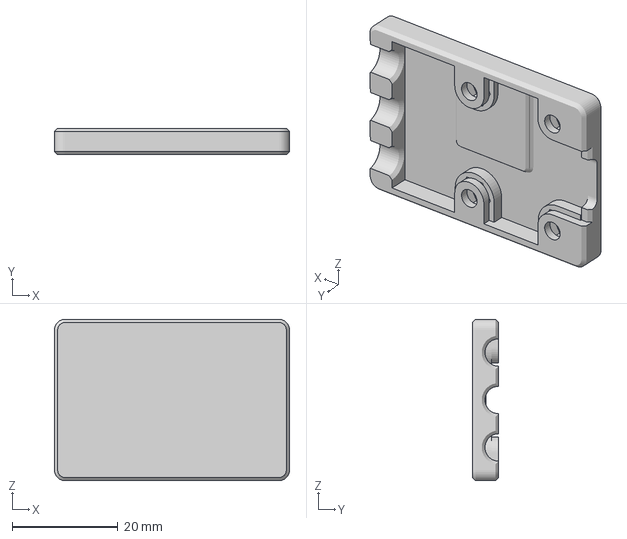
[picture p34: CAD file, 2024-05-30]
Enclosure/Lower-enclosure-thermal-pad.3mf
44.5 x 5.00 x 30.6 mm

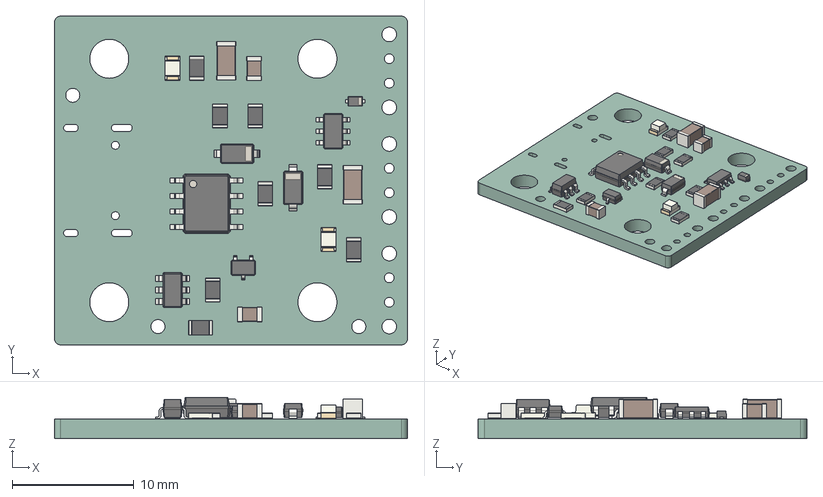
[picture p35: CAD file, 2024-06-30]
USB-C-splitter.step
29.0 x 27.0 x 3.40 mm
SOT_323_SC_70
R_0805_2012Metric x 8
SOIC_8_39x49mm_P127mm
C_1206_3216Metric x 2
D_SOD_123 x 2
LED_0805_2012Metric x 2
C_0805_2012Metric x 2
TSOT_23_6
D_SOD_523
SOT_23_6
USB-C-3-way-splitter_PCB

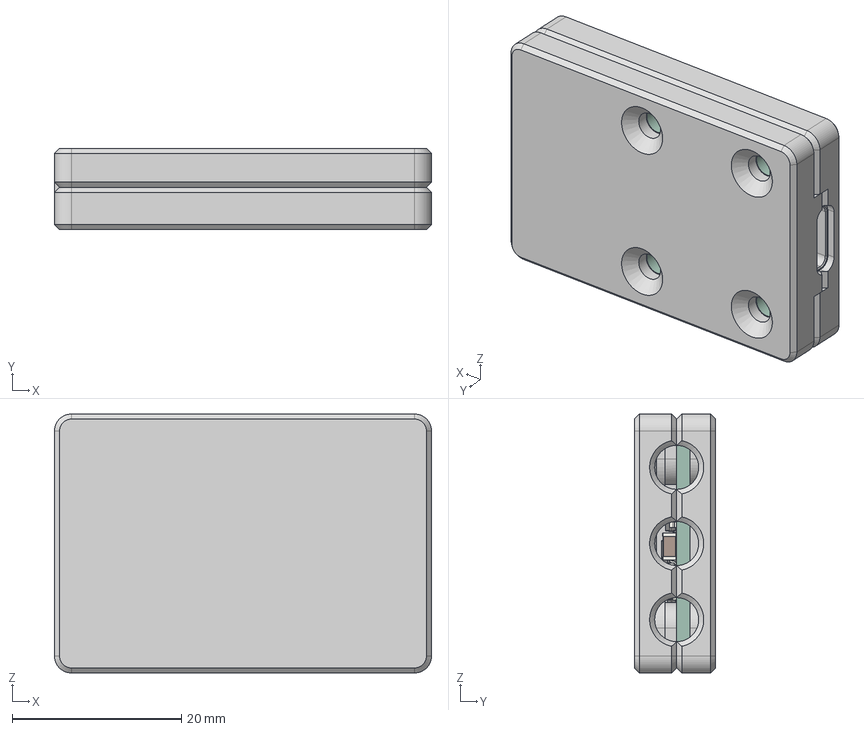
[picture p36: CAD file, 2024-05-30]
Enclosure/Enclosure design V2 thermal pad.step
44.5 x 9.60 x 30.6 mm
Lower-enclosure
Upper-enclosure
SOT_323_SC_70
R_0805_2012Metric x 8
SOIC_8_39x49mm_P127mm
C_1206_3216Metric x 2
D_SOD_123 x 2
LED_0805_2012Metric x 2
C_0805_2012Metric x 2
TSOT_23_6
_autosave-USB-C-3-way-splitter_PCB
TYPE-C-31-M-12

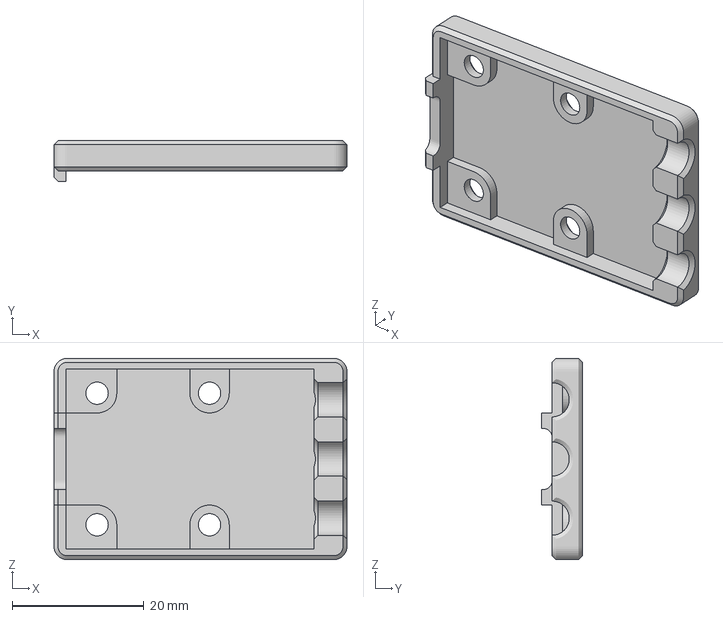
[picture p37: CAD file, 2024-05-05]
Enclosure/Upper-enclosure.3mf
44.5 x 6.20 x 30.6 mm

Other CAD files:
Enclosure/Lower-enclosure-potted.3mf
Enclosure/Enclosure design V2 potted.step
Enclosure/Enclosure design V2 potted.f3z
Enclosure/Enclosure design V2 thermal pad.f3z

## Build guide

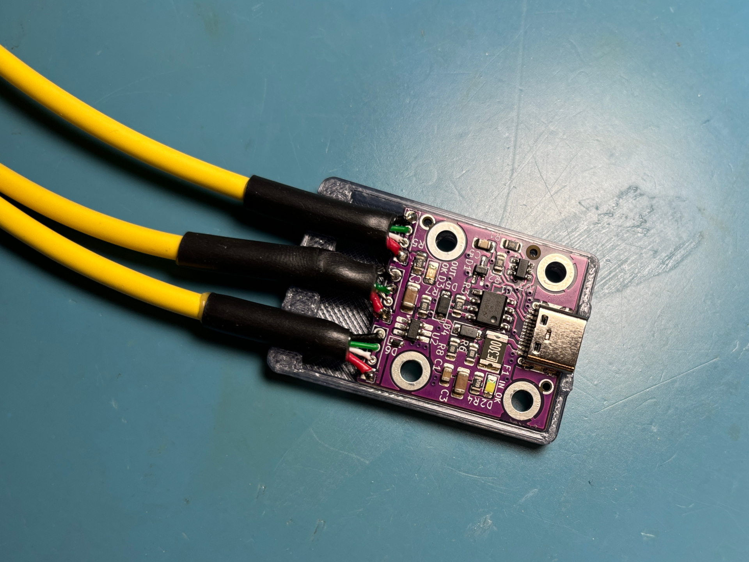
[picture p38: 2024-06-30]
Graphics/Build guide/17.JPG

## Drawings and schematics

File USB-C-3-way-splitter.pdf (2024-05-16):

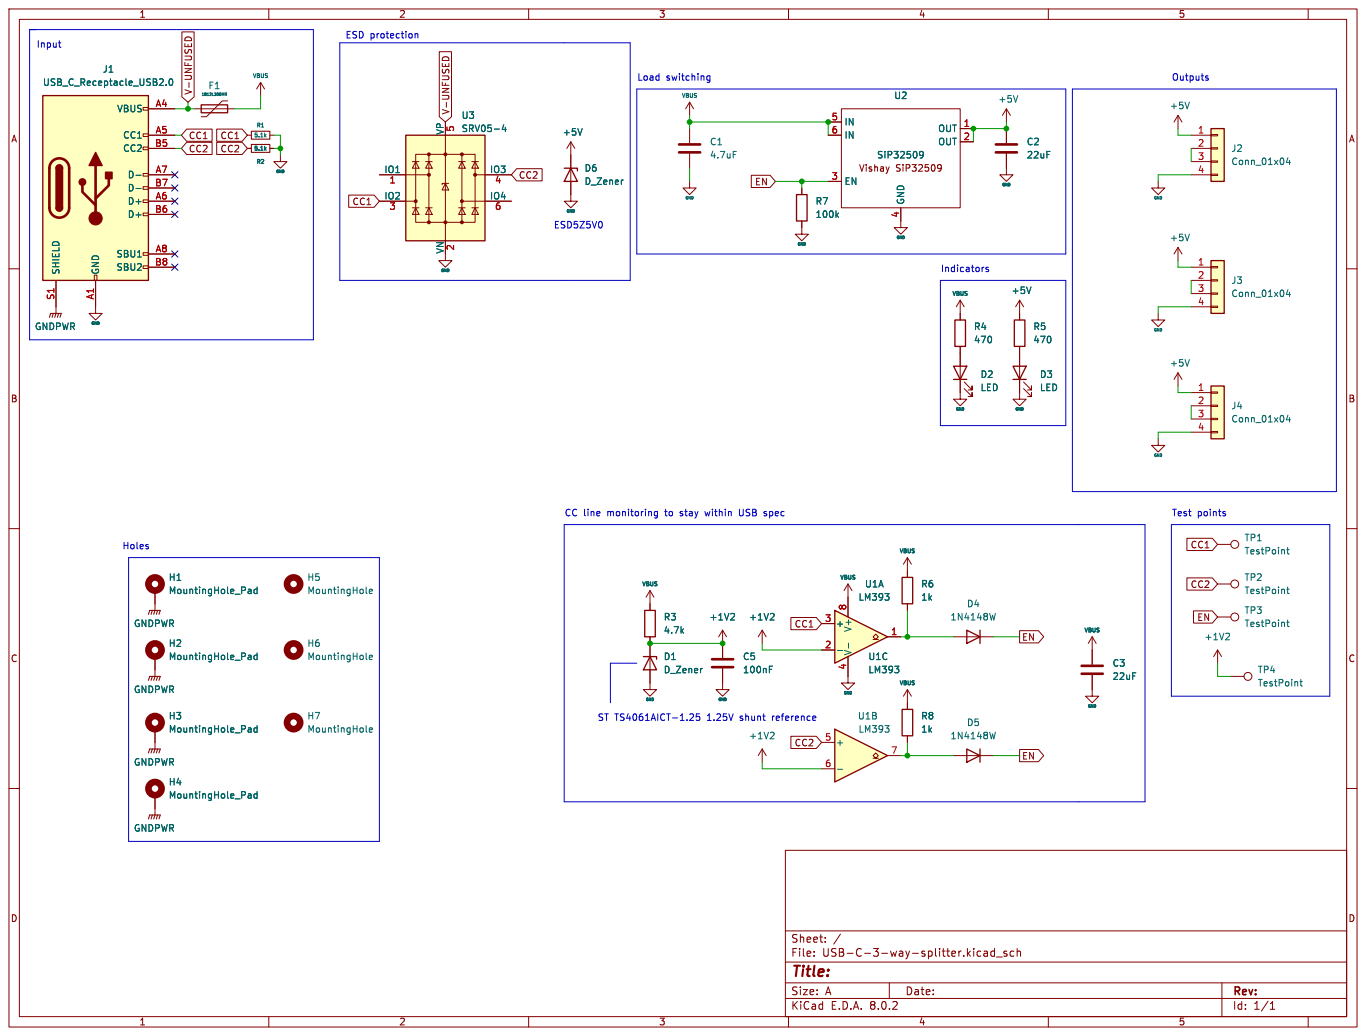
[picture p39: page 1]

Id: 1/1 Title: File: USB-C-3-way-splitter.kicad_sch Sheet: /

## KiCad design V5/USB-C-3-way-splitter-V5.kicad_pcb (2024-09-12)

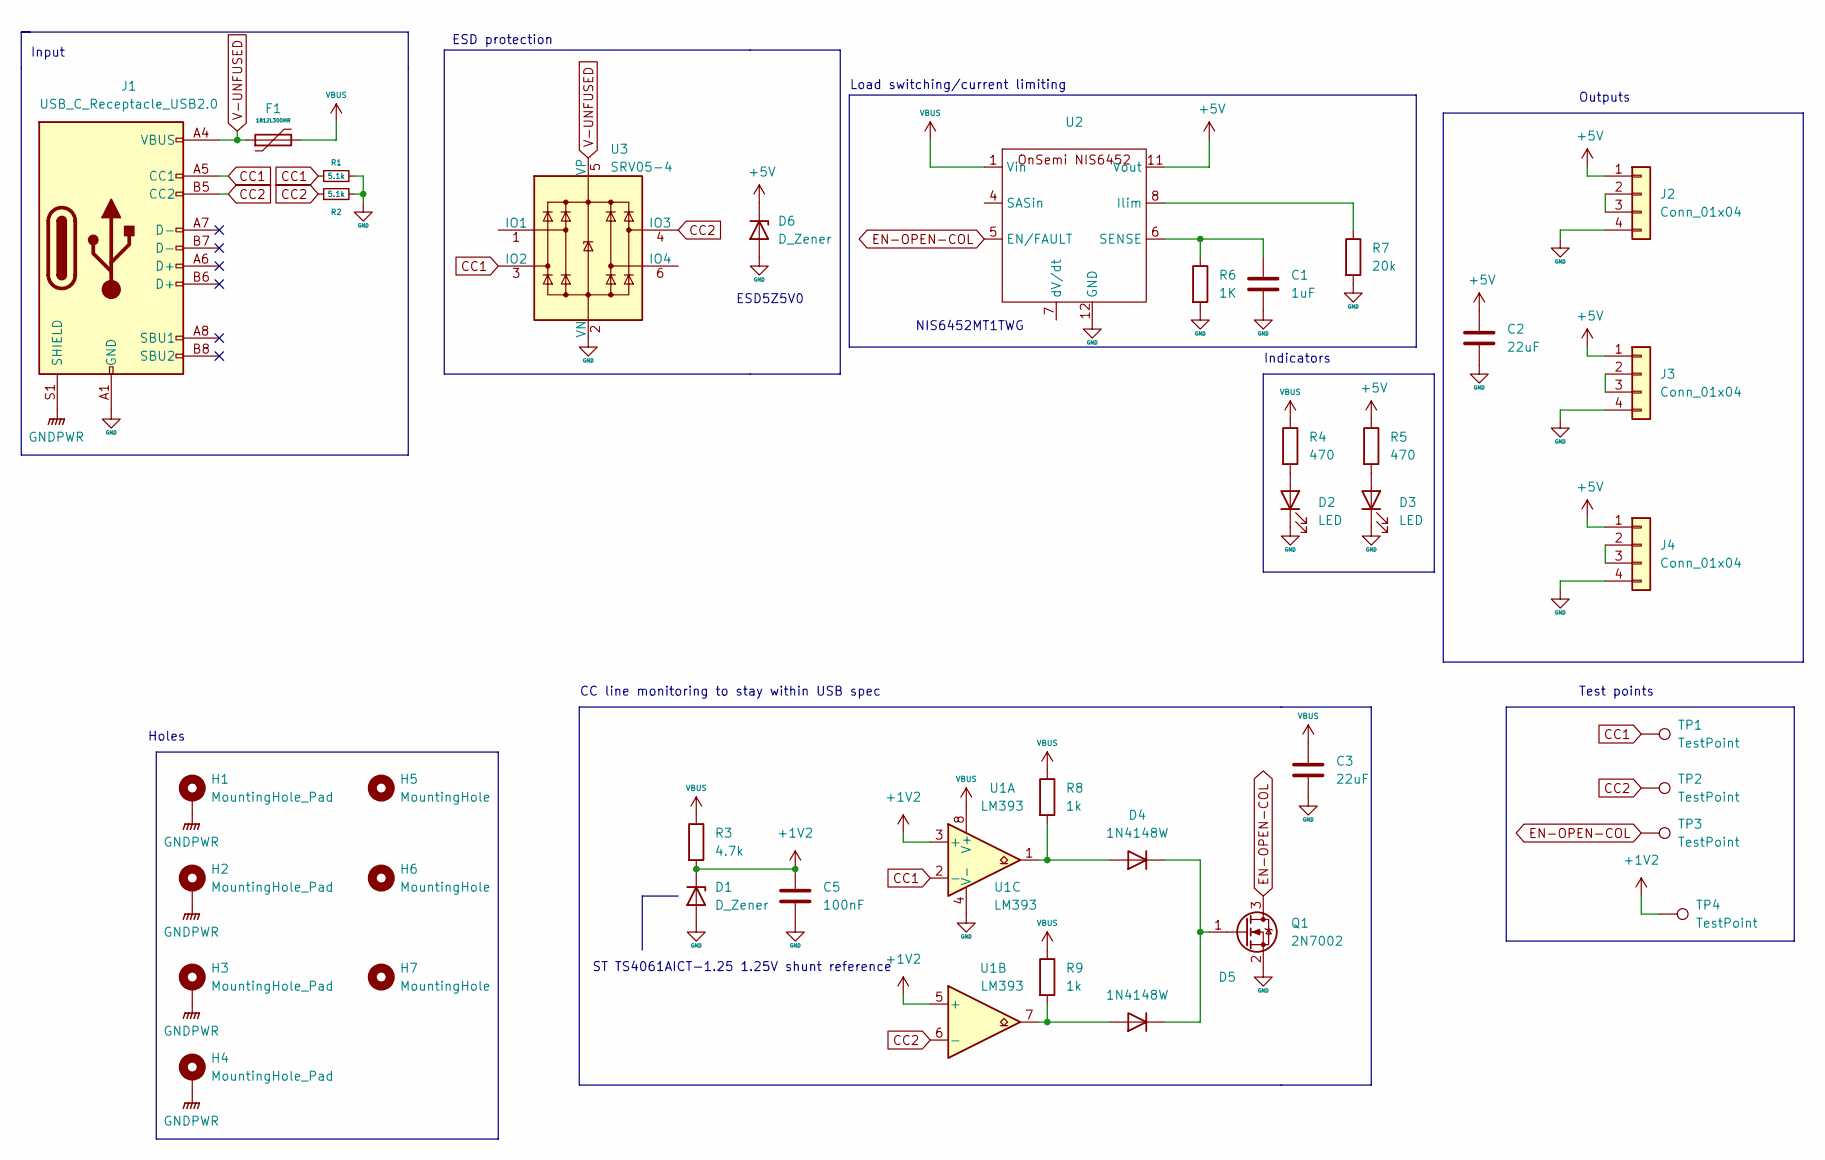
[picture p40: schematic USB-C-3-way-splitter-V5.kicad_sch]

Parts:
C1: 1uF; C_0805_2012Metric_Pad1.18x1.45mm_HandSolder
C2, C3: 22uF; C_1206_3216Metric_Pad1.33x1.80mm_HandSolder
C5: 100nF; C_0805_2012Metric_Pad1.18x1.45mm_HandSolder
D1: D_Zener; SOT-323_SC-70_Handsoldering
D2, D3: LED; LED_0805_2012Metric_Pad1.15x1.40mm_HandSolder
D4, D5: 1N4148W; D_SOD-123
D6: D_Zener; D_SOD-523
F1: 1812L300MR; Fuse_1812_4532Metric_Pad1.30x3.40mm_HandSolder; Manufacturer Part No ASMD1206-150; LCSC Part No C135342
H1, H2, H3, H4: MountingHole_Pad; MountingHole_3.2mm_M3_ISO7380_Pad
H5, H6, H7: MountingHole; JLCPCB-tooling-hole
J1: USB_C_Receptacle_USB2.0; USB_C_Receptacle_HRO_TYPE-C-31-M-12; LCSC C165948
J2, J3, J4: Conn_01x04; PinHeader_1x04_P2.00mm_Vertical
Q1: 2N7002; SOT-23
R1, R2: 5.1k; R_0805_2012Metric_Pad1.20x1.40mm_HandSolder
R3: 4.7k; R_0805_2012Metric_Pad1.20x1.40mm_HandSolder
R4, R5: 470; R_0805_2012Metric_Pad1.20x1.40mm_HandSolder
R6: 1K; R_0805_2012Metric_Pad1.20x1.40mm_HandSolder
R7: 20k; R_0805_2012Metric_Pad1.20x1.40mm_HandSolder
R8, R9: 1k; R_0805_2012Metric_Pad1.20x1.40mm_HandSolder
TP1, TP2, TP3, TP4: TestPoint; TestPoint_Pad_D2.5mm
U1: LM393; SOIC-8_3.9x4.9mm_P1.27mm
U2: OnSemi-WQFN12-3x2mm_P0.5mm
U3: SRV05-4; SOT-23-6

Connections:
+1V2: C5.1, D1.1 (K), R3.2, TP4.1, U1.3 (+), U1.5 (+)
+5V: C2.1, D6.1 (K), J2.1, J3.1, J4.1, R5.1, U2.9 (Vout), U2.10 (Vout), U2.11 (Vout)
CC1: J1.A5 (CC1), R1.1, TP1.1, U1.2 (-), U3.3 (IO2)
CC2: J1.B5 (CC2), R2.1, TP2.1, U1.6 (-), U3.4 (IO3)
EN-OPEN-COL: Q1.3 (D), TP3.1, U2.5 (EN/FAULT)
GND: C1.2, C2.2, C3.2, C5.2, D1.2 (A), D2.1 (K), D3.1 (K), D6.2 (A), J1.A1 (GND), J1.A12 (GND), J1.B1 (GND), J1.B12 (GND), J2.4, J3.4, J4.4, Q1.2 (S), R1.2, R2.2, R6.2, R7.2, U1.4 (V-), U2.12 (GND), U2.13 (GND), U3.2 (VN)
GNDPWR: H1.1, H2.1, H3.1, H4.1, J1.S1 (SHIELD)
unnamed: D2.2 (A), R4.2
unnamed: D3.2 (A), R5.2
unnamed: D4.2 (A), R8.2, U1.1
unnamed: D4.1 (K), D5.1 (K), Q1.1 (G)
unnamed: D5.2 (A), R9.2, U1.7
unnamed: J2.2, J2.3
unnamed: J3.2, J3.3
unnamed: J4.2, J4.3
unnamed: R7.1, U2.8 (Ilim)
unnamed: C1.1, R6.1, U2.6 (SENSE)
V-UNFUSED: F1.1, J1.A4 (VBUS), J1.A9 (VBUS), J1.B4 (VBUS), J1.B9 (VBUS), U3.5 (VP)
VBUS: C3.1, F1.2, R3.1, R4.1, R8.1, R9.1, U1.8 (V+), U2.1 (Vin), U2.2 (Vin), U2.3 (Vin)

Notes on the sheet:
ESD protection
ST TS4061AICT-1.25 1.25V shunt reference
Input
NIS6452MT1TWG
CC line monitoring to stay within USB spec
Indicators
ESD5Z5V0
Outputs
Load switching/current limiting
Test points
Holes

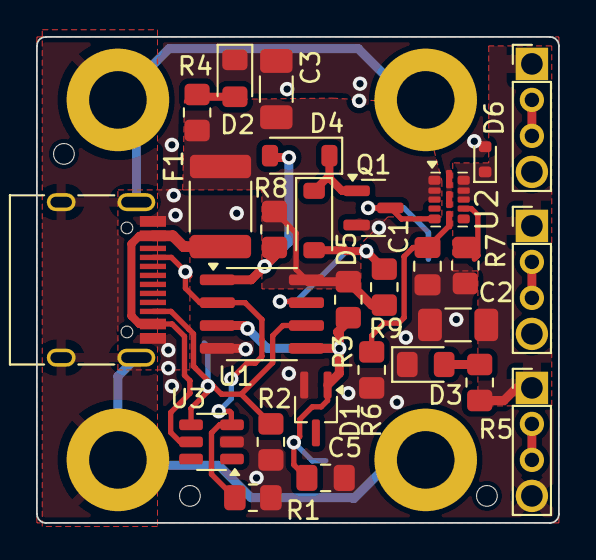
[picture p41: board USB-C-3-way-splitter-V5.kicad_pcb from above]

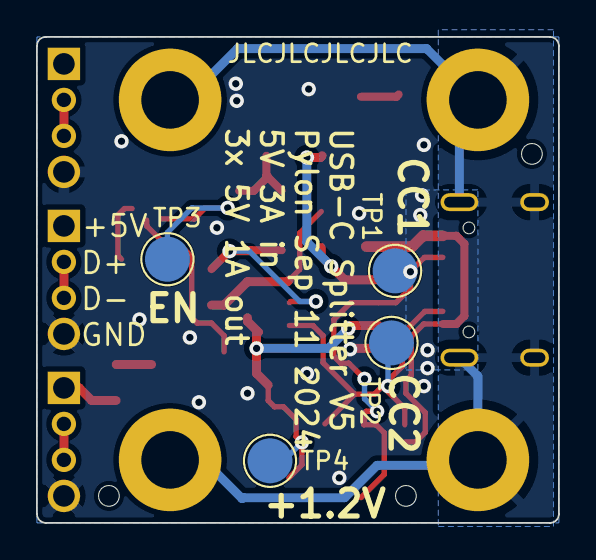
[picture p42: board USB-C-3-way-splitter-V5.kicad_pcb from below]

Board: 2 copper layers, 29.0 x 27.0 mm, 39 parts (4 on the bottom side), 19 nets.

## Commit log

2024-02-14 Moved everything on the 5v rail to after the fuse
    [USB-C-3-way-splitter.kicad_pcb, USB-C-3-way-splitter.kicad_sch]
2024-02-14 Made Gerbers
    [USB-C-3-way-splitter-B_Cu.gbr, USB-C-3-way-splitter-B_Mask.gbr, USB-C-3-way-splitter-B_Paste.gbr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]
2024-02-14 Open-collectors are inverting ugh. Fixed comparator in schematic.
    [USB-C-3-way-splitter.kicad_sch]
2024-02-14 Layout is incorrect (had to fix schematic)
    [USB-C-3-way-splitter-B_Cu.gbr, USB-C-3-way-splitter-B_Mask.gbr, USB-C-3-way-splitter-B_Paste.gbr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]
2024-02-14 Never mind misunderstood the LM393M's behavior
    [USB-C-3-way-splitter.kicad_pcb, USB-C-3-way-splitter.kicad_sch]
2024-02-15 Design is done maybe?
    [JLCPCB-BOM.xls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]
2024-02-15 Added JLCPCB tooling holes
    [USB-C-3-way-splitter-B_Cu.gbr, USB-C-3-way-splitter-B_Mask.gbr, USB-C-3-way-splitter-B_Paste.gbr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]
2024-02-15 Added schematic
2024-02-15 Added pulldown to EN, added test points
    [JLCPCB-BOM.xls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]
2024-02-15 Removed unnecessary diodes and resistor
    [JLCPCB-BOM.xls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]
2024-03-10 Added enclosure design
    [Enclosure.f3z, Enclosure.step]
2024-03-10 Reorg, status update, added case
    [Enclosure.f3z, Enclosure.step, Lower-housing.3mf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]
2024-03-11 Design updates
    [Enclosure.f3z, Enclosure.step, Lower-housing.3mf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]
2024-04-13 Redesigned to fix circuit design error
    The previous revision had the comparator outputs implemented as an AND instead of an OR, which was preventing the switch from ever turning on.
    [USB-C-3-way-splitter.kicad_pcb, USB-C-3-way-splitter.kicad_sch]
2024-04-13 Added label
    [USB-C-3-way-splitter.kicad_pcb]
2024-04-13 Minor silkscreen revisions
    [USB-C-3-way-splitter.kicad_pcb]
2024-04-13 Updated design files for V2
    [Enclosure.f3z, Enclosure.step, JLCPCB-BOM.xls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]
2024-04-14 Added STEP file of the PCB
    [USB-C-splitter.step]
2024-04-18 Rev 2 after Rev 1 did not work
    [USB-C-3-way-splitter.kicad_pcb, USB-C-3-way-splitter.step]
2024-05-04 Updated files
    [Enclosure design V2 v7.f3z, Enclosure design V2.step, Lower-enclosure.3mf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]
2024-05-05 Fixed board thickness
    [Enclosure design V2 potted.f3z, Enclosure design V2 v7.f3z, Enclosure design V2.f3z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]
2024-05-16 Added V3, updated README
    [JLCPCB-BOM.xls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]
2024-05-30 Revised enclosure
    [Enclosure design V2 potted.step, Enclosure design V2 thermal pad.f3z, Enclosure design V2 thermal pad.step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]
2024-06-29 Some organization and updates
    [JLCPCB-BOM.xls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]
2024-06-30 A bit of reorganization; adding graphics
    [JLCPCB-BOM.xls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]
2024-06-30 Updated the STEP file
    [USB-C-splitter.step]
2024-07-08 Work on V4
    [USB-C-3-way-splitter-V4.kicad_pcb, USB-C-3-way-splitter-V4.kicad_sch]
2024-07-08 More work on V4
    [JLCPCB-BOM.xls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]
2024-08-20 Updated on Version 4
    [JLCPCB-BOM.xls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]
2024-09-12 Started a V5
    [JLCPCB-BOM.xls, USB-C-3-way-splitter-V5.kicad_pcb, USB-C-3-way-splitter-V5.kicad_sch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]
2025-04-13 Work on V5
    [JLCPCB-CPL.xls, USB-C-3-way-splitter-V5-B_Cu.gbr, USB-C-3-way-splitter-V5-B_Mask.gbr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]
2025-04-13 Fixed rotation on U2
    [JLCPCB-CPL.xls]
